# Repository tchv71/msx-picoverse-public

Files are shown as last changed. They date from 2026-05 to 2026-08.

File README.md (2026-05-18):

# PicoVerse for MSX

**The MSX experience driven by the Raspberry Pi Pico family of microcontrollers.**

PicoVerse is a community-driven effort to build versatile MSX cartridges powered by Raspberry Pi Pico development boards. The project pairs accessible hardware designs with ready-to-flash firmware so MSX users can jump straight into loading games, tools, and Nextor without having to compile sources.

| Cartridge Label - 2040 Variant | Cartridge Label - 2350 Variant |
|---|---|
|PicoVerse 2040 Label | PicoVerse 2350 Label |

PicoVerse is designed as an open-source, independent, and documented MSX cartridge platform. Compatibility with other projects is neither a goal nor guaranteed (I tested some without much success); running third‑party software on PicoVerse hardware, or PicoVerse firmware on other boards, is at your own risk. The source and manufacturing files are openly available so you can learn, experiment, and build on them for the MSX community, subject to the project license.

If you find any issues, have questions, or want to contribute, please open an issue or reach out via the contact information in the repository.

## Project Highlights

- Single-ROM LoadROM workflow for instant and easy booting of one title.
- Multi-ROM loader with an on-screen menu and mapper auto-detection.
- Explorer firmware (PicoVerse 2350) merges flash and microSD ROMs, labels the source (FL/SD), adds MP3 playback, supports on-device search, includes ROM detail audio profiles with SCC/SCC+ and Dual PSG support, and includes an integrated File Hunter browser for downloading ROMs over ESP-01 WiFi.
- Ready-made Nextor builds with USB pendrive (`-s2`/`-m2`) or microSD card (`-s1`/`-m1`) via Sunrise IDE emulation on PicoVerse 2350, and USB (`-s`/`-m`) on PicoVerse 2040.
- Sunrise IDE + 192KB memory mapper on PicoVerse 2040 (`loadrom.exe -m`), or Sunrise IDE standalone (`loadrom.exe -s`).
- Sunrise IDE + 1MB PSRAM memory mapper on PicoVerse 2350 (`loadrom.exe -m1` for microSD, `loadrom.exe -m2` for USB), or Sunrise IDE standalone (`loadrom.exe -s1` / `loadrom.exe -s2`).
- Carnivore2-compatible RAM-mode loader on PicoVerse 2350 (`loadrom.exe -c1` / `loadrom.exe -c2`) for `SROM.COM /D15` uploads into the 1MB PSRAM mapper.
- ESP-01 WiFi support for PicoVerse 2350 Sunrise IDE LoadROM/MultiROM builds (`loadrom.exe -s1 -w`, `-m1 -w`, `-s2 -w`, `-m2 -w`) and for the Explorer File Hunter browser. Compatible with both real MSX hardware and FPGA-based MSX cores.
- SCC/SCC+, Dual PSG, and MSX-MUSIC/YM2413 emulation on the PicoVerse 2350, with per-ROM audio profile selection where supported.
- PC-side tooling that generates UF2 images locally for quick drag-and-drop flashing.
- USB keyboard support on PicoVerse 2040 — use a standard USB keyboard as the MSX keyboard via the cartridge slot.
- MSX-MIDI support on PicoVerse 2040 — use a USB-MIDI cable as a standard MSX-MIDI interface via the cartridge slot. 
- MIDI-PAC support on PicoVerse 2040 — passively convert live MSX PSG music and effects into high-quality MIDI for external synths or sound modules (SC-55 optimized). Features automatic bass detection, tone+noise coexistence, smooth pitch bending on fast passages, and improved percussion mapping. 
- USB joystick support on PicoVerse 2040 — plug a standard USB gamepad (HID, Xbox 360, Xbox One, or Xbox Series X|S) into the USB-C port and it appears as one or two native MSX joysticks with no MSX-side software needed. Uses open-drain bus driving to coexist with the real PSG.
- BOMs, and production-ready Gerbers.
- Active development roadmap covering RP2040 and RP2350-based cartridges.

## Documentation

**LoadROM Guides:** Use the LoadROM tool to create a UF2 image that boots directly into a single ROM, skipping the menu. Mapper type is auto-detected with filename tag overrides, and the tool reports the detected configuration before flashing.
- [MSX PicoVerse 2040 LoadROM Tool Manual (English)](/docs/msx-picoverse-2040-loadrom-tool-manual.en-us.md) 
- [MSX PicoVerse 2350 LoadROM Tool Manual (English)](/docs/msx-picoverse-2350-loadrom-tool-manual.en-us.md) 
  
**MultiROM Guides:** Use the MultiROM tool to create a UF2 image that allows selecting from multiple ROMs at boot. Mapper type is auto-detected with filename tag overrides, and the tool reports the detected configuration before flashing.
- [PicoVerse 2040 MultiROM Guide Manual (English)](/docs/msx-picoverse-2040-multirom-tool-manual.en-us.md)
- [PicoVerse 2350 MultiROM Tool Manual (English)](/docs/msx-picoverse-2350-multirom-tool-manual.en-us.md)

**Explorer Guides:** Use the Explorer tool to manage flash and microSD ROMs, play MP3s, browse File Hunter over ESP-01 WiFi, and search for titles on the device.
- [MSX PicoVerse 2350 Explorer Tool Manual (English)](/docs/msx-picoverse-2350-explorer-tool-manual.en-us.md)

**Reference Material** 
- [PicoVerse 2040 Features Overview](/docs/msx-picoverse-2040-features.md)
- [PicoVerse 2350 Features Overview](/docs/msx-picoverse-2350-features.md)
- [MSX PicoVerse 2350 Dual PSG Implementation](/docs/msx-picoverse-2350-dualpsg.md)
- [MSX PicoVerse 2350 MSX-MUSIC/FM-PAC Implementation](/docs/msx-picoverse-2350-fmpac.md)
- [MSX PicoVerse 2350 WiFi Support](/docs/msx-picoverse-2350-wifi.md)
- [MSX PicoVerse 2040 PIO Strategy](/docs/msx-picoverse-2040-pio.md) 
- [MSX PicoVerse 2350 PIO Strategy](/docs/msx-picoverse-2350-pio.md) 
- [MSX PicoVerse 2350 SCC Emulation](/docs/msx-picoverse-2350-scc.md)
- [MSX PicoVerse 2040 Sunrise IDE Emulation for Nextor](/docs/msx-picoverse-2040-sunrise-nextor.md) 
- [MSX PicoVerse 2350 Sunrise IDE Emulation for Nextor](/docs/msx-picoverse-2350-sunrise-nextor.md) 
- [MSX PicoVerse 2040 Mapper Implementation (Sunrise + Nextor)](/docs/msx-picoverse-2040-mapper.md) 
- [MSX PicoVerse 2040 USB Keyboard](/docs/msx-picoverse-2040-keyboard.md)
- [MSX PicoVerse 2040 MSX-MIDI](/docs/msx-picoverse-2040-msx-midi.md) 
- [MSX PicoVerse 2040 MIDI-PAC](/docs/msx-picoverse-2040-midipac.md)
- [MSX PicoVerse 2040 MegaROMs](/docs/msx-picoverse-2040-megaroms.md)
- [MSX PicoVerse 2040 USB Joystick](/docs/msx-picoverse-2040-joystick.md)

## Hardware Variants

### PicoVerse 2040 Cartridge

| Prototype PCB (front) | Prototype PCB (back) |
|---|---|
|  |  | 

- Based on RP2040 boards exposing 30 GPIO pins (not compatible with stock Raspberry Pi Pico pinout).
- Up to 16 MB of flash for MSX ROMs with support for Plain16/32 (`PLA-16`/`PLA-32`), Planar48/64 (`PLN-48`/`PLN-64`), Konami SCC, Konami, ASCII8/16/16X, NEO-8, NEO-16, and Manbow2 (`MANBW2`) mappers.
- USB-C port doubles as a bridge for Nextor mass storage via Sunrise IDE emulation (`loadrom.exe -s`).
- Sunrise IDE + 192KB memory mapper mode provides both Nextor disk access and expanded RAM (`loadrom.exe -m`).
- Standalone USB keyboard firmware — use a standard USB keyboard as the MSX keyboard via the cartridge slot (`loadrom.exe -k`). Not compatible with FPGA-based MSX systems or MSX computers with an integrated PPI (e.g. T9769 MSX-ENGINE).
- Standalone MSX-MIDI firmware — use a USB-MIDI cable as a standard MSX-MIDI interface for MIDI players and sequencers (`loadrom.exe -i`).
- Standalone MIDI-PAC firmware — passively listen to the MSX PSG and convert music and effects to USB MIDI for an external synth or sound module (`loadrom.exe -p`).
- Standalone USB joystick firmware — use a standard USB gamepad as an MSX joystick via the cartridge slot (`loadrom.exe -j`). Supports Xbox 360, Xbox One, Xbox Series X|S, and generic USB HID gamepads, with up to 2 gamepads mapped to MSX joystick ports 1 and 2.  Not compatible with FPGA-based MSX systems or MSX computers with an integrated PSG (e.g. T9769 MSX-ENGINE).

#### Bill of Materials



Interactive BOM available at [PicoVerse 2040 BOM](https://htmlpreview.github.io/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)

| Reference | Description | Quantity | Link |
| --- | --- | --- | --- |
| U1 | RP2040 Dev Board 30 GPIO pins exposed | 1 | [AliExpress](https://s.click.aliexpress.com/e/_c4MuM9st) |
| C1 | 0603 0.1 µF Ceramic Capacitor | 1 | [AliExpress](https://s.click.aliexpress.com/e/_c2w5e36V) |
| C2 | 0603 10 µF Ceramic Capacitor | 1 | [AliExpress](https://s.click.aliexpress.com/e/_c2w5e36V)|
| R2, R3, R4, R5, R6, R7, R8, R9, R10, R11, R12, R13| 0603 10 kΩ Resistor | 12 | [AliExpress](https://s.click.aliexpress.com/e/_c3XBv4od)|
| R1 | 0603 2 KΩ Resistor | 1 | [AliExpress](https://s.click.aliexpress.com/e/_c3XBv4od)|
| D1 | 1N5819 SOD-123 Diode | 1 | [AliExpress](https://s.click.aliexpress.com/e/_c4WEKCuz) |
| Q1, Q2, Q3, Q4, Q5 | BSS138 SOT-23 Transistor | 5 | [AliExpress](https://s.click.aliexpress.com/e/_c2veWxcD)|

### PicoVerse 2350 Cartridge

| Prototype PCB (front) | Prototype PCB (back) |
|---|---|
|  |  |

- Targets RP2350 boards exposing all 48 GPIO pins (not compatible with standard Pico 2 boards).
- Adds microSD storage, ESP8266 WiFi header, and I2S audio expansion alongside 16 MB flash space.
- Extra RAM (PSRAM) now backs the 1MB mapper modes and the Carnivore2-compatible RAM loader, with room for additional advanced firmware features.
- Explorer firmware can load ROMs from both flash and microSD, browse File Hunter over ESP-01 WiFi, save downloaded File Hunter ROMs to the microSD root, search local title lists, and select SCC/SCC+ or Dual PSG audio profiles per ROM where supported.
- USB-C port doubles as a bridge for Nextor mass storage via Sunrise IDE emulation (`-s2`).
- microSD card slot provides Nextor mass storage via Sunrise IDE emulation (`-s1`).
- Sunrise IDE + 1MB PSRAM memory mapper mode provides both Nextor disk access and expanded RAM (`-m1` for microSD, `-m2` for USB).
- Carnivore2-compatible RAM-mode loading lets `SROM.COM /D15` upload ROMs into the 1MB PSRAM mapper (`-c1` for microSD, `-c2` for USB).
- LoadROM Sunrise builds can also expose ESP-01 WiFi support with `-w` on top of the `-s1`/`-m1`/`-s2`/`-m2` modes.
- Both LoadROM and MultiROM tools support the Sunrise IDE options; MultiROM allows combining them so multiple Nextor modes appear as selectable SYSTEM entries in the menu.
- Shares the same ROM mapper support list as the 2040 build.

#### Bill of Materials



Interactive BOM available at [PicoVerse 2350 BOM](https://htmlpreview.github.io/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) 

| Reference | Description | Quantity | Link |
| --- | --- | --- | --- |
| U1 | WaveShare Core2350B Dev Board 48 GPIO pins exposed (8Mb PSRAM)| 1 | [AliExpress](https://pt.aliexpress.com/item/1005009578742534.html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) |
|U2| UDA1334A I2S Stereo DAC| 1 | [AliExpress](https://s.click.aliexpress.com/e/_c3gam5lH) |
|U3| ESP-01 ESP8266 WiFi Module| 1 | [AliExpress](https://s.click.aliexpress.com/e/_c4a5rnGj) |
|C1| 0603 0.1 µF Ceramic Capacitor | 1 | [AliExpress](https://s.click.aliexpress.com/e/_c3tkUxHz) |
|C2,C3| 0603 10 µF Ceramic Capacitor | 2 | [AliExpress](https://s.click.aliexpress.com/e/_c3tkUxHz)|
|R1| 0603 2 KΩ Resistor | 1 | [AliExpress](https://s.click.aliexpress.com/e/_c43uKcEj)|
|R2, R3, R6, R7, R8| 0603 10 kΩ Resistor | 4 | [AliExpress](https://s.click.aliexpress.com/e/_c43uKcEj)|
|R4, R5| 0603 5.1 kΩ Resistor | 2 | [AliExpress](https://s.click.aliexpress.com/e/_c43uKcEj)|
|R9, R10| 0603 330 Ω Resistor | 2 | [AliExpress](https://s.click.aliexpress.com/e/_c43uKcEj)|
|D1| 1N5819 SOD-123 Diode | 1 | [AliExpress](https://s.click.aliexpress.com/e/_c4WEKCuz) |
|SW1| Tactile Push Button Switch | 1 | [AliExpress](https://s.click.aliexpress.com/e/_c2IPGkzv) |
|J1| USB-C 16 Pin Connector | 1 | [AliExpress](https://s.click.aliexpress.com/e/_c4PtBc51) |
|J2| microSD Card Slot | 1 | [AliExpress](https://s.click.aliexpress.com/e/_c4Pzbd7Z) |

## Repository Contents
- `hardware/` – Production-ready Gerbers, fabrication notes, and BOMs for each supported dev board.
- `software/` – MultiROM PC utilities (`multirom.exe`) and menu ROM assets for both cartridge families.
- `docs/` – Feature lists, usage walkthroughs, and revision history for each cartridge family.
- `images/` – Board renders and build photos for quick identification.
- `labels/` – Printable Patola style cartridge label designs for both hardware variants.

## Quick Start
1. **Pick your target board**: Select the hardware revision that matches the RP2040 or RP2350 carrier you own, then grab the corresponding Gerber/BOM pack.
2. **Manufacture or assemble**: Send the Gerbers to your PCB house or build from an ordered kit. Follow the assembly notes included in each hardware bundle.
3. **Generate the UF2 image**:
   - For multiple titles, place your `.rom` files beside the MultiROM tool for your cartridge family (`2040/software/multirom.pio/tool/multirom.exe` or `2350/software/multirom.pio/tool/multirom.exe`) and run `multirom.exe` to create `multirom.uf2`.
   - For an instant boot into a single game, place the desired `.rom` next to the LoadROM tool for your cartridge family and run `loadrom.exe <file> [-o custom.uf2]` to create a dedicated UF2 that skips the menu.
   - For a combined flash + microSD menu (on PicoVerse 2350 only), use the Explorer tool (`2350/software/explorer.pio/tool/explorer.exe`) to create `explorer.uf2`, then copy extra `.rom` and `.mp3` files to the microSD card. With an ESP-01 module and configured WiFi, Explorer can also browse File Hunter and save downloaded ROMs directly to the microSD root.
4. **Flash the firmware**:
   - Hold BOOTSEL while connecting the cartridge to your PC via USB-C.
   - Copy the freshly generated UF2 (`multirom.uf2`, `loadrom.uf2`, or `explorer.uf2`) to the RPI-RP2 drive that appears.
   - Eject the drive; the board reboots and stores the image in flash.
5. **Enjoy on MSX**: Insert the cartridge, power on the computer, pick a ROM from the menu, or launch Nextor to access USB or microSD storage.

## MultiROM Menu

| PicoVerse 2040 MultiRom | PicoVerse 2350 MultiRom |
|---|---|
|PicoVerse 2040 MultiROM menu|PicoVerse 2350 MultiROM menu|

To use the MultiROM menu, insert the PicoVerse cartridge into your MSX and power it on. The system will boot directly into the MultiROM menu, which displays a list of all ROMs embedded in the cartridge. Each entry is named after the ROM filename (up to 50 characters), and longer names are shown using a scrolling effect.

Navigate the menu using the keyboard arrow keys. Use the Up and Down keys to move through the list of ROMs, and if more than 19 ROMs are present, use the Left and Right keys to switch between pages. To start a game or application, select it and press Enter or Space; the MSX will boot the ROM using the appropriate mapper configuration automatically.

While in the menu, pressing the H key opens a help screen with basic instructions; press any key to return to the main menu. Once a ROM is launched, control is handed over entirely to the selected software, just as if it were a physical cartridge inserted into the MSX.

Check the detailed MultiROM guide in the documentation folder for advanced features, troubleshooting tips, and mapper support details.

## LoadROM Tool

The LoadROM tool targets situations where you want the PicoVerse to behave like a traditional single-game cartridge or as a dedicated standalone firmware image. Instead of showing the MultiROM menu, the Pico boots straight into one ROM embedded in the UF2 image, or into a selected standalone mode such as keyboard, MSX-MIDI, MIDI-PAC, or USB joystick.

- **Input**: exactly one `.ROM` file. Mapper type is auto-detected with the same heuristics as MultiROM, and you can still force a mapper via filename tags such as `.KonSCC.ROM` or `.PLA-32.ROM`.
- **Output**: `loadrom.uf2` by default, or any filename you pass via `-o`. The UF2 contains the firmware, a 59-byte configuration record (title, mapper, size, flash offset), and the ROM payload.
- **Workflow**:
   1. Open a Command Prompt or PowerShell window in your target package folder:
      - `2040/software/loadrom.pio/tool`, or
      - `2350/software/loadrom.pio/tool`.
   2. Run `loadrom.exe -o mygame.uf2 \\path\\to\\Game.ROM` (the tool also accepts drag-and-drop onto the EXE).
      - MSX-MIDI standalone mode: `loadrom.exe -i -o midi.uf2`
      - MIDI-PAC standalone mode: `loadrom.exe -p -o midipac.uf2`
      - USB joystick standalone mode: `loadrom.exe -j -o joystick.uf2`
      - SCC standard emulation (only PicoVerse 2350): `loadrom.exe -scc \\path\\to\\Game.ROM`
      - SCC+ enhanced emulation (only PicoVerse 2350): `loadrom.exe -sccplus \\path\\to\\Game.ROM`
      - MSX-MUSIC/FM-PAC emulation with the bundled English FM-PAC BIOS (only PicoVerse 2350, non-SYSTEM ROMs): `loadrom.exe -f \\path\\to\\Game.ROM`, `loadrom.exe -fmpac \\path\\to\\Game.ROM`, or `loadrom.exe --fmpac -o mygame-fmpac.uf2 \\path\\to\\Game.ROM`
      - Dual PSG emulation on secondary PSG ports `0x10`/`0x11` (only PicoVerse 2350, supported non-SYSTEM ROMs): `loadrom.exe -d \\path\\to\\Game.ROM` or `loadrom.exe --dual-psg -o mygame-dualpsg.uf2 \\path\\to\\Game.ROM`
      - `-scc` and `-sccplus` are mutually exclusive.
      - `-scc`, `-sccplus`, `-f` / `-fmpac`, and `-d` / `--dual-psg` are cartridge audio modes; use only one of them per UF2.
      - `-f` / `-fmpac` is not valid with Sunrise or Carnivore2 system modes (`-s1`, `-m1`, `-s2`, `-m2`, `-c1`, or `-c2`) or with Konami SCC / Manbow2 mapper ROMs.
      - `-d` / `--dual-psg` is intended for software that writes to a second PSG. It is not available for Konami SCC or Manbow2 mapper ROMs, SCC/SCC+ audio builds, Sunrise/Nextor system modes, or Carnivore2 system modes.
      - Sunrise IDE standalone (PicoVerse 2040): `loadrom.exe -s`
      - Sunrise IDE + 192KB mapper (PicoVerse 2040): `loadrom.exe -m`
      - Sunrise IDE standalone (PicoVerse 2350): `loadrom.exe -s1` or `loadrom.exe -s2`
      - Sunrise IDE + 1MB PSRAM mapper (PicoVerse 2350): `loadrom.exe -m1` or `loadrom.exe -m2`
      - Sunrise IDE + WiFi (PicoVerse 2350): `loadrom.exe -s1 -w`, `loadrom.exe -s2 -w`, `loadrom.exe -m1 -w`, or `loadrom.exe -m2 -w`
      - Carnivore2-compatible RAM loader (PicoVerse 2350): `loadrom.exe -c1` or `loadrom.exe -c2`
      - `-w` is currently supported only with `-s1`, `-m1`, `-s2`, or `-m2`.
   3. Observe the reported ROM name, size, mapper status (auto vs forced), and Pico offset before the UF2 is written.
   4. Put the Pico into BOOTSEL mode and copy the generated UF2 to the `RPI-RP2` drive.
   5. Insert the cartridge into your MSX—on power-up the embedded game launches immediately.

Consult the LoadROM manuals linked above for screenshots, troubleshooting, and in-depth explanations of mapper forcing, UF2 structure, and limitations.

## Explorer Firmware (RP2350)

|Explorer Flash Menu|Explorer MicroSD Menu|
|---|---|
|Explorer flash menu|Explorer microSD menu|
|<center>**File Hunter Explorer Menu**|<center>**WiFi Configuration Screen**|
|File Hunter Explorer menu|WiFi configuration screen|

Explorer is a PicoVerse 2350-only firmware that merges ROMs stored in flash with additional ROMs and MP3 files on the microSD card. ROMs are labeled with source tags (FL/SD), MP3 entries open a player screen, the list supports paging, and you can search by name directly in the menu. With an ESP-01 / ESP8266 module installed and WiFi configured, pressing `F3` opens the integrated File Hunter browser. File Hunter results show the ROM name and size, can be searched from the MSX, and selected ROMs are downloaded through the Pico into PSRAM before being saved as `.ROM` files in the microSD root. microSD ROMs up to 2 MB can be executed directly from there. Use the Explorer tool to build the UF2 and copy extra ROMs and MP3 files to the microSD card. See the Explorer manual for limits (flash vs SD capacity, 2 MB SD ROM limit, File Hunter requirements, and supported formats).

You can have up to 1024 entries per folder view (folders + ROMs + MP3s; the root view can also include flash entries). The menu auto-detects whether the MSX supports 80-column text mode and boots accordingly; you can also press `C` at any time to toggle between 40- and 80-column layouts.

Explorer ROM entries open a detail screen where you can inspect mapper detection and choose a cartridge audio profile. For supported non-SYSTEM ROMs, select **Dual PSG** and run the ROM to enable the second cartridge-side PSG on ports `0x10` and `0x11`. Explorer hides or rejects Dual PSG where the second cartridge audio slot is reserved, including Konami SCC, Manbow2, SYSTEM entries, folders, and File Hunter folder records. 

A search function is available by pressing `/` in the menu. Type part of a ROM name and press Enter to jump to the first matching entry. Press `H` to view the help screen.

The File Hunter browser was implemented with reference to NataliaPC's public MSX File Hunter Browser project: https://github.com/nataliapc/msx_filehunterbrowser

## Compatibility & Requirements

- Works with MSX, MSX2, MSX2+, and MSX TurboR systems. Mapper support covers the most common game and utility formats.
- Requires Windows OS to run the PC-side UF2 builder utilities.
- Ensure your development board matches the pinout documented for each hardware revision before soldering.

## License, Copyright notes & Usage

Creative Commons Attribution-NonCommercial-ShareAlike 4.0

All hardware and firmware binaries in this repository are released under the Creative Commons Attribution-NonCommercial-ShareAlike 4.0 International license. Personal builds and community tinkering are encouraged, but **commercial use or resale requires explicit authorization from the author**.

**bios.h** is used on all MSX menus and was adapted from http://www.konamiman.com/msx/msx2th/th-ap.txt by Danilo Angelo, 2020. The original file is licensed under CC0 1.0 Universal (public domain). The adapted bios.h file in this repository is also released under CC0 1.0 Universal, allowing for free use and modification without restrictions.

**msxromcrt0.s** is used on Nextor C implementation and was adapted by S0urceror, 2022, from the crt0.s file available in FusionC v2.0. The original crt0.s file is licensed under the MIT License. The adapted msxromcrt0.s file in this repository is also released under the MIT License, permitting free use, modification, and distribution with proper attribution.

**uf2format.h** is used in all UF2 builder tools and was adapted from the UF2 specification and reference implementation available at https://github.com/Microsoft/uf2/blob/master/uf2.h. The original uf2.h is copyright by Microsoft Corp and the file is licensed under the MIT License. The adapted uf2format.h file in this repository is also released under the MIT License, allowing for free use, modification, and distribution with proper attribution.

**emu2212.c** and **emu2212.h** used to implement SCC and SCC+ emulation are copyright by Mitsutaka Okazaki 2014 and licensed under the MIT License, allowing for free use, modification, and distribution with proper attribution. [emu2212 @ Digital Sound Antiques](https://github.com/digital-sound-antiques/emu2212)

**emu2149.c** and **emu2149.h** used to implement AY-3-8910 emulation/dual PSG feature are copyright by Mitsutaka Okazaki 2014 and licensed under the MIT License, allowing for free use, modification, and distribution with proper attribution. [emu2149 @ Digital Sound Antiques](https://github.com/digital-sound-antiques/emu2149)

**emu2413.c** and **emu2413.h** used to implement YM2413 / MSX-MUSIC emulation are copyright by Mitsutaka Okazaki 2020 and licensed under the MIT License, allowing for free use, modification, and distribution with proper attribution. [emu2413 @ Digital Sound Antiques](https://github.com/digital-sound-antiques/emu2413)

**FMPCCMFC.BIN** is the English FM-PAC BIOS used by PicoVerse 2350 LoadROM when `-f` / `-fmpac` is selected. The FM-PAC BIOS ROM is copyrighted by Matsushita Corp.; the English translation is credited to 232, Max Iwamoto, and GDX.

**MIDI-PAC PSG-to-MIDI Conversion:**  
The MIDI-PAC firmware and its quality improvements were developed against public technical references and behavior studies. The PSG-to-MIDI mapping combines hardware-correct AY-3-8910 / YM2149 interpretation with pragmatic General MIDI reinterpretation for musical output on modules like the Roland SC-55. Key references used include:  
- The `berarma/aymidi` project by berarma (AY-3-8910 to MIDI conversion reference).  
- The `ayumi` AY/YM2149 emulator by Peter Sovietov (Peter Sovietov, 2022; used for envelope generation verification).  
- The ESEMSX3 FPGA implementation `midi.vhd` (serves as a minimal alternative PSG-to-MIDI transport reference).  
- AY-3-8910 and YM2149 datasheets and hardware behavior documentation (General Instruments and Yamaha specifications).  
- MSX-MIDI specification and USB MIDI 1.0 Event Packet format (USB Implementers Forum).  
- The Sunrise IDE specification and Nextor protocol documentation.  

These references informed structure, timing, envelope shapes, and musical mapping decisions. The PicoVerse firmware maintains its own implementation with no dependencies on external emulation libraries. The PicoVerse files are licensed under CC BY-NC-SA 4.0, allowing for non-commercial use and modification with proper attribution, but commercial use or resale requires explicit authorization from the author.

**MSX-MIDI Interface:**  
The MSX-MIDI firmware was developed using the MSX-MIDI specification, USB MIDI 1.0 specification, TinyUSB host API, and reference behavior from ESEMSX3 and similar implementations. The 8251 USART emulation and standard MIDI wire protocol handling are original PicoVerse implementations.

**The Sunrise IDE driver for Nextor** used on PicoVerse is copyright by Konamiman, Piter Punk, and FRS, and is licensed under the special terms by MSX Licensing Corporation. The original Sunrise IDE code is available at https://github.com/Konamiman/Nextor/blob/v2.1/source/kernel/drivers/SunriseIDE/sunride.asm

The algorithm to emulate ATA devices is original and based on the implementation for the Carnivore2 cartridge, Copyright (c) 2017-2024 by the RBSC group. Portions (c) Mitsutaka Okazaki and (c) Kazuhiro Tsujikawa. Available at https://github.com/RBSC/Carnivore2/tree/master/Firmware/Sources

**WiFi support on PicoVerse 2350** was implemented with direct reference to the ESP8266 / MSX WiFi work by Oduvaldo Pavan Junior (`ducasp`). The PicoVerse WiFi ROM integration, memio register layout, fixed-`859372` UART behavior, FIFO clear command handling, quick-receive behavior, and ESP-side protocol compatibility were based on public source and documentation from Oduvaldo's projects. Important references used include:
- `MSXPICO/UNAPI_BIOS_CUSTOM_ESP_MSXPICO/ESP8266_memio.asm` from `ducasp/MSX-Development` for the memory-mapped ROM and register model.
- `MSX-SM/WiFi/UNAPI_BIOS_CUSTOM_ESP_FIRMWARE` and related WiFi utilities from `ducasp/MSX-Development` for the ROM/driver lineage and behavior.
- `ducasp/ESP8266-UNAPI-Firmware` and its documentation for the serial protocol, command/response structure, and ESP firmware behavior.

Those projects remain copyright by Oduvaldo Pavan Junior and their respective contributors under their original terms. PicoVerse reuses the public technical design references and keeps its own RP2350 cartridge-side implementation.

**File Hunter browser integration on PicoVerse 2350 Explorer** was implemented with reference to NataliaPC's MSX File Hunter Browser project and the public File Hunter service behavior. PicoVerse keeps its own Explorer MSX menu and RP2350/ESP8266 transport implementation, while acknowledging the original MSX File Hunter Browser code and workflow by NataliaPC. Reference repository: https://github.com/nataliapc/msx_filehunterbrowser

**Mapper detection heuristics and filename tag forcing schemes** in the LoadROM and MultiROM tools are original implementations by the OpenMSX developers for the Romfactory module and licensed under the GNU Public License (GPL). Available at https://github.com/openMSX/openMSX/blob/6f8aa9865eeccdb0b31043d8851b822538440204/src/memory/RomFactory.cc

**The softwaredb database** used for ROM mapper detection is built upon contributions from across the MSX community, including the initial work by Nicolas Beyaert, later expanded by the BlueMSX Team (2004–2013) and continuously maintained by the openMSX Team (2005–present). It also incorporates MSX ID data generated by Generation MSX (www.generation-msx.nl). Special thanks go to the Generation MSX / Sylvester project for its extensive reference data, as well as to contributors such as p_gimeno and diedel for ROM additions and validation, and GDX for further ROM information, corrections, and verification efforts. Part of OpenMSX effort. Available at https://github.com/openMSX

## Feedback & Community

Questions, test reports, and build photos are welcome. Open an issue on the public repository or reach out through the MSX retro hardware forums where PicoVerse updates are posted.

Author: Cristiano Goncalves
Last updated: 05/17/2026

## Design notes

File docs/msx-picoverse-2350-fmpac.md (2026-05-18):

# MSX PicoVerse 2350 - MSX-MUSIC / FM-PAC Implementation

The PicoVerse 2350 LoadROM firmware can emulate the MSX-MUSIC YM2413 sound chip and expose an FM-PAC compatible BIOS area for games that do not drive the YM2413 directly. This is enabled by the LoadROM tool options `-f`, `-fmpac`, or `--fmpac` when building a UF2 for a non-SYSTEM external ROM.

The implementation has two parts:

- Pico-side YM2413 synthesis using the emu2413 OPLL emulator and the PicoVerse I2S DAC.
- FM-PAC BIOS exposure in the cartridge slot so software that uses MSX-MUSIC BIOS calls can find the BIOS routines and reach the emulated OPLL.

This document describes the RP2350 LoadROM implementation in `2350/software/loadrom.pio`.

---

## Goals

The FM-PAC/MSX-MUSIC support was added for ROMs that expect MSX-MUSIC hardware to be present on the cartridge. Some titles write directly to the YM2413 I/O ports, while others use BIOS routines or FM-PAC memory-mapped registers. The firmware supports both access styles.

The design goals are:

- Keep MSX-MUSIC as a single cartridge audio profile, mutually exclusive with SCC, SCC+, and Dual PSG.
- Allow `-f` / `-fmpac` with supported non-SYSTEM external ROM mappers, excluding SCC-class mappers.
- Embed the FM-PAC BIOS in the UF2 image, immediately after the game ROM payload.
- Present the selected game ROM mapper and the FM-PAC BIOS in one expanded cartridge slot layout.
- Route both direct YM2413 I/O writes and FM-PAC memory-mapped register writes to the same OPLL emulator instance.

---

## User-facing behavior

### Command-line options

```
loadrom.exe -f <romfile>
loadrom.exe -fmpac <romfile>
loadrom.exe --fmpac <romfile>
```

All three options enable the same feature. The tool prints:

```
MSX-MUSIC/FM-PAC Emulation: Enabled with BIOS and YM2413 ports 0x7C/0x7D
```

### Valid combinations

`-f` / `-fmpac` is valid only with non-SYSTEM external ROM files. It is rejected for the embedded Sunrise/Carnivore2 system modes (`-s1`, `-m1`, `-s2`, `-m2`, `-c1`, `-c2`) and for Konami SCC or Manbow2 mapper ROMs.

Only one cartridge audio engine can be active in a UF2 image. The tool rejects combinations of:

- `-scc`
- `-sccplus`
- `-d` / `--dual-psg`
- `-f` / `-fmpac` / `--fmpac`

Konami SCC and Manbow2 mapper ROMs are not accepted for `-f` / `-fmpac` builds.

---

## Source files

### Tool side

| File | Role |
| --- | --- |
| `2350/software/loadrom.pio/tool/src/loadrom.c` | Parses `-f` / `-fmpac`, sets the MSX-MUSIC flag, appends the FM-PAC BIOS payload, and writes the UF2. |
| `2350/software/loadrom.pio/tool/Makefile` | Generates `tool/src/fmpac_bios.h` from `../fmpac/FMPCCMFC.BIN` using `utils/xxd -i`. |
| `2350/software/loadrom.pio/tool/src/fmpac_bios.h` | Generated C array containing the 64 KB FM-PAC BIOS. |
| `2350/software/loadrom.pio/fmpac/FMPCCMFC.BIN` | English FM-PAC BIOS binary embedded into `-f` / `-fmpac` UF2 images. |

### Firmware side

| File | Role |
| --- | --- |
| `2350/software/loadrom.pio/pico/loadrom/loadrom.c` | Implements audio mode selection, YM2413 initialization, direct I/O handling, FM-PAC register handling, and the expanded-slot FM-PAC mapper wrapper. |
| `2350/software/loadrom.pio/pico/loadrom/loadrom.h` | Defines MSX-MUSIC flags, ports, clocks, sample rate, and FM-PAC BIOS size. |
| `2350/software/loadrom.pio/pico/loadrom/emu2413.c` | YM2413/OPLL emulator implementation. |
| `2350/software/loadrom.pio/pico/loadrom/emu2413.h` | YM2413/OPLL emulator API. |
| `2350/software/loadrom.pio/pico/loadrom/CMakeLists.txt` | Includes `emu2413.c` in the LoadROM firmware build. |

---

## Build integration

The top-level LoadROM build is driven by `2350/software/loadrom.pio/Makefile`.

The PC tool build depends on the FM-PAC BIOS binary:

```
FMPAC_BIOS := ../fmpac/FMPCCMFC.BIN
FMPAC_BIOS_H := $(SRCDIR)/fmpac_bios.h
```

The header is generated with the local `xxd` utility:

```
$(FMPAC_BIOS_H): $(FMPAC_BIOS)
	$(UTLDIR)/$(XXD) -i $< $@
```

The generated symbol names are:

```
___fmpac_FMPCCMFC_BIN[]
___fmpac_FMPCCMFC_BIN_len
```

The current BIOS payload length is 65536 bytes.

---

## UF2 payload layout

LoadROM UF2 images are written by `create_uf2_file()` in the tool. With `-f` / `-fmpac`, the binary stream is:

| Order | Payload | Description |
| --- | --- | --- |
| 1 | Firmware blob | RP2350 LoadROM firmware from `pico/loadrom/dist/loadrom.bin`. |
| 2 | Configuration record | 59-byte record containing ROM name, mapper/audio flags, ROM size, and ROM flash offset. |
| 3 | Game ROM | The external ROM file passed on the command line. |
| 4 | FM-PAC BIOS | `FMPCCMFC.BIN`, appended only when MSX-MUSIC/FM-PAC is enabled. |

The firmware uses the game ROM size from the configuration record to find the BIOS:

```
fmpac_bios_base = rom + offset + active_rom_size
```

This keeps the existing ROM payload format intact while reusing the extra embedded ROM mechanism already used by other LoadROM modes.

---

## Configuration flags

The configuration record stores mapper and audio selection in one byte. For non-SYSTEM ROMs, bit `0x20` is used as the MSX-MUSIC flag:

| Bit | Firmware constant | Meaning in non-SYSTEM ROM builds |
| --- | --- | --- |
| `0x80` | `SCC_FLAG` | SCC emulation requested. |
| `0x40` | `SCC_PLUS_FLAG` | SCC+ emulation requested. |
| `0x20` | `MSX_MUSIC_FLAG` | MSX-MUSIC / FM-PAC requested. |
| `0x10` | `DUAL_PSG_FLAG` | Dual PSG requested. |
| `0x0F` | Base mapper ID | Selected ROM mapper. |

The same `0x20` bit is used as `WIFI_FLAG` in Sunrise system modes. The firmware distinguishes those cases by checking the base ROM type and resolving `system_mode` before selecting an audio engine.

---

## Audio mode selection

The firmware resolves cartridge audio through `resolve_audio_mode()`.

The modes are:

| Mode | Meaning |
| --- | --- |
| `AUDIO_MODE_NONE` | No Pico-side cartridge audio engine. |
| `AUDIO_MODE_SCC` | Standard SCC emulation. |
| `AUDIO_MODE_SCC_PLUS` | SCC+ emulation. |
| `AUDIO_MODE_DUAL_PSG` | Secondary AY-3-8910 on ports `0x10`/`0x11`. |
| `AUDIO_MODE_MSX_MUSIC` | YM2413/MSX-MUSIC on ports `0x7C`/`0x7D` plus FM-PAC BIOS exposure. |

System ROM modes always resolve to `AUDIO_MODE_NONE` for this path. Because the tool enforces mutual exclusion, a valid `-f` / `-fmpac` image contains only the MSX-MUSIC flag and therefore resolves to `AUDIO_MODE_MSX_MUSIC`.

When `AUDIO_MODE_MSX_MUSIC` is selected, `main()` initializes the YM2413 engine and then dispatches to `loadrom_fmpac()` before the normal mapper switch.

---

## YM2413 / OPLL audio engine

### Emulation library

The firmware uses emu2413 by Mitsutaka Okazaki. Initialization creates one OPLL instance:

```
OPLL_new(MSX_MUSIC_CLOCK, MSX_MUSIC_SAMPLE_RATE)
OPLL_setChipType(..., OPLL_2413_TONE)
OPLL_resetPatch(..., OPLL_2413_TONE)
```

The LoadROM constants are:

| Constant | Value |
| --- | --- |
| `MSX_MUSIC_CLOCK` | 3579545 Hz |
| `MSX_MUSIC_SAMPLE_RATE` | 44100 Hz |
| `MSX_MUSIC_PORT_REG` | `0x7C` |
| `MSX_MUSIC_PORT_DATA` | `0x7D` |

### Core usage

| Core | Role |
| --- | --- |
| Core 0 | Serves the MSX memory bus through PIO0 and routes FM-PAC memory-mapped writes to the OPLL. |
| Core 1 | Generates YM2413 audio, services direct OPLL I/O writes from PIO1, and feeds the I2S DAC. |

The audio path uses the existing PicoVerse I2S output on GPIOs 29-32:

| Signal | GPIO |
| --- | --- |
| DATA | 29 |
| BCLK | 30 |
| WSEL / LRCLK | 31 |
| MUTE | 32 |

### Locking

Both direct I/O writes and memory-mapped FM-PAC writes can reach the OPLL while core 1 is calculating audio samples. The firmware protects the OPLL instance with a Pico SDK spin lock:

- `msx_music_calc_sample()` locks around `OPLL_calc()`.
- `msx_music_write_io()` locks around `OPLL_writeIO()`.

This keeps core 0 register writes and core 1 audio generation from mutating the emulator state at the same time.

---

## Direct YM2413 I/O handling

The firmware initializes a PIO1 I/O bus captor with `msx_pio_io_bus_init()` when MSX-MUSIC is enabled.

`msx_music_service_io()` consumes captured I/O writes. Writes to ports `0x7C` and `0x7D` are forwarded to:

```
msx_music_write_io(port, data)
```

I/O reads are acknowledged with `0xFF`. The YM2413 path currently only needs write capture for register select and data writes.

When audio generation is running on core 1, direct I/O servicing is owned by core 1. This prevents missed port writes while core 0 is busy serving ROM or mapper cycles.

---

## FM-PAC expanded slot model

The firmware presents FM-PAC builds as an expanded cartridge slot. This follows the same general strategy used by Sunrise/Carnivore2-style expanded-slot modes, but with the game mapper and FM-PAC BIOS sharing the slot.

`loadrom_fmpac()` starts by waiting for the expanded-slot bootstrap, freezes the bus with `/WAIT`, prepares the ROM source/cache, then reinitializes the PIO0 MSX memory bus.

The expanded slot layout is:

| Subslot | Function |
| --- | --- |
| 0 | Selected game ROM mapper. |
| 1 | Unused, returns `0xFF`. |
| 2 | Unused, returns `0xFF`. |
| 3 | FM-PAC BIOS, FM-PAC control/page registers, PAC SRAM window, and memory-mapped OPLL write registers. |

The expanded slot selection register is handled at address `0xFFFF`. Writes update the local `subslot_reg`; reads return the inverted value, matching the standard expanded-slot register behavior.

For each read or write, the firmware computes the active subslot for the current 16 KB page:

```
page = address >> 14
active_subslot = (subslot_reg >> (page * 2)) & 0x03
```

If the active subslot is 0, the access is routed to the game mapper. If the active subslot is 3, the access is routed to the FM-PAC handler.

---

## FM-PAC memory map

The FM-PAC side is modeled by `fmpac_state_t`:

| Field | Purpose |
| --- | --- |
| `page` | Low two bits select one 16 KB page from the 64 KB BIOS. |
| `control` | Value stored by writes to `0x7FF6`; initialized to `0x10`. |
| `sram_key_5ffe` | First PAC SRAM enable key byte. |
| `sram_key_5fff` | Second PAC SRAM enable key byte. |
| `sram[8192]` | Volatile 8 KB PAC SRAM window. |

### Registers and windows

| Address/range | Access | Behavior |
| --- | --- | --- |
| `0x4000`-`0x7FFF` | Read | FM-PAC BIOS page selected by `0x7FF7`, unless PAC SRAM is enabled for `0x4000`-`0x5FFF`. |
| `0x4000`-`0x5FFF` | Read/write | Volatile PAC SRAM when keys `0x5FFE = 0x4D` and `0x5FFF = 0x69` are active. |
| `0x5FFE` | Write | Stores PAC SRAM key byte `0x4D`. |
| `0x5FFF` | Write | Stores PAC SRAM key byte `0x69`. |
| `0x7FF4` | Write | FM-PAC memory-mapped YM2413 register select; forwarded as port `0x7C`. |
| `0x7FF5` | Write | FM-PAC memory-mapped YM2413 data; forwarded as port `0x7D`. |
| `0x7FF6` | Read/write | FM-PAC control register shadow. |
| `0x7FF7` | Read/write | BIOS page register; low two bits select one of four 16 KB pages. |

The BIOS lookup is:

```
relative = ((page & 0x03) << 14) | (address & 0x3FFF)
```

Because `FMPAC_BIOS_SIZE` is 65536 bytes, the four pages cover the whole embedded BIOS.

---

## Supported game mappers inside FM-PAC mode

`loadrom_fmpac()` keeps the selected game mapper active in subslot 0. The mapper ID is still selected by the normal LoadROM detection/forcing path; `-f` / `-fmpac` only changes the audio and slot wrapper.

| Mapper ID | Mapper | FM-PAC wrapper behavior |
| --- | --- | --- |
| 1 | Plain 16 KB | Serves the fixed ROM window through the plain mapper path. |
| 2 | Plain 32 KB | Serves the fixed ROM window through the plain mapper path. |
| 3 | Konami SCC mapper | Not supported for FM-PAC/MSX-MUSIC builds. |
| 4 | Planar 48 KB | Serves the linear 48 KB style address range. |
| 5 | ASCII8 | Uses 8 KB ASCII bank registers. |
| 6 | ASCII16 | Uses 16 KB ASCII bank registers. |
| 7 | Konami | Uses Konami 8 KB bank registers. |
| 8 | NEO8 | Uses six 8 KB NEO bank registers. |
| 9 | NEO16 | Uses three 16 KB NEO bank registers. |
| 12 | ASCII16-X | Uses the ASCII16-X bank register layout for mirrored 16 KB pages. |
| 13 | Planar 64 KB | Serves the full 64 KB address space linearly. |
| 14 | Manbow2 | Not supported for FM-PAC/MSX-MUSIC builds. |

For unmapped subslots or unsupported windows, reads return `0xFF`.

---

## Access flow examples

### Direct YM2413 write

1. Z80 writes to I/O port `0x7C` or `0x7D`.
2. PIO1 captures the I/O write.
3. Core 1 drains the I/O FIFO while generating audio.
4. `msx_music_write_io()` forwards the write to emu2413.
5. Core 1 continues producing PCM samples for the I2S DAC.

### FM-PAC BIOS call path

1. Game calls MSX-MUSIC BIOS routines.
2. The MSX slot selection targets the FM-PAC subslot for the BIOS page.
3. Firmware reads bytes from the embedded `FMPCCMFC.BIN` image.
4. BIOS code writes FM-PAC OPLL registers at `0x7FF4` / `0x7FF5`, or direct ports depending on the routine.
5. Firmware forwards those writes to the same emu2413 OPLL instance.

### Game mapper access

1. Game selects the primary game subslot for its cartridge pages.
2. Firmware routes reads and mapper writes to the selected mapper implementation.
3. The game ROM continues to run from its normal mapper while the FM-PAC BIOS remains available from subslot 3.

---

## Compatibility notes

- `-f` and `-fmpac` are synonyms in the LoadROM tool.
- The feature is currently implemented for RP2350 LoadROM (`2350/software/loadrom.pio`).
- The FM-PAC BIOS is embedded into every `-f` / `-fmpac` non-SYSTEM external ROM UF2.
- ROMs that directly write YM2413 ports `0x7C`/`0x7D` are supported.
- ROMs that rely on MSX-MUSIC BIOS calls are supported by the embedded FM-PAC BIOS exposure.
- ROMs that use FM-PAC memory-mapped OPLL registers `0x7FF4`/`0x7FF5` are routed to the same YM2413 emulator.
- Konami SCC and Manbow2 mapper ROMs are rejected for FM-PAC/MSX-MUSIC builds.
- Audio is generated by the PicoVerse I2S DAC, not by the host MSX audio circuit.

---

## Limitations

- Only one Pico-side cartridge audio engine is active per UF2 image. MSX-MUSIC cannot be combined with SCC, SCC+, or Dual PSG in the same image.
- FM-PAC/MSX-MUSIC is not enabled for embedded Sunrise/Carnivore2 system modes.
- PAC SRAM is volatile. It is modeled in RAM and is not persisted across power cycles.
- The FM-PAC BIOS payload is an embedded third-party BIOS binary; distribution and use must respect the rights of the BIOS copyright holders.
- The implementation models the FM-PAC BIOS/register behavior needed by LoadROM titles, not a complete standalone FM-PAC cartridge with persistent SRAM management.

---

## Validation performed

The implementation was validated with the LoadROM build flow:

```
make firmware
make tool
```

The tool was also checked with an R-Type build:

```
loadrom.exe -fmpac -o rtype_fmpac.uf2 "R-Type - IREM.rom"
```

The generated output reported ASCII8 mapper detection, MSX-MUSIC/FM-PAC enablement with BIOS and ports `0x7C`/`0x7D`, and a larger UF2 due to the appended 64 KB BIOS payload.

Invalid combinations were checked to ensure the option rules still reject mutually exclusive audio modes and SYSTEM builds.

---

## Credits

- YM2413/OPLL emulation uses emu2413 by Mitsutaka Okazaki, licensed under the MIT License.
- `FMPCCMFC.BIN` is the English FM-PAC BIOS. The FM-PAC BIOS ROM is copyrighted by Matsushita Corp.; the English translation is credited to 232, Max Iwamoto, and GDX.

---

Author: Cristiano Almeida Goncalves

Last updated: 05/17/2026

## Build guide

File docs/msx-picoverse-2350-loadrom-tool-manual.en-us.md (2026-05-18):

# MSX PicoVerse 2350 LoadROM Tool Manual (EN-US)

The PicoVerse 2350 cartridge can boot either a MultiROM menu or a single ROM that starts immediately. The LoadROM tool creates a UF2 image that flashes the PicoVerse 2350 with a single ROM payload and the LoadROM firmware.

`loadrom.exe` bundles the Pico firmware blob, a configuration record (game name, mapper code, ROM size, and flash offset), and one MSX ROM file into an RP2350-compatible UF2 image. Copy the generated UF2 to the board in BOOTSEL mode and the MSX will boot straight into the embedded ROM.

For RP2350, the current LoadROM package is:

- `2350/software/loadrom.pio`.

> **Important:** SCC/SCC+ emulation options (`-scc`, `-sccplus`), the secondary AY-3-8910 dual PSG option (`-d`), and the MSX-MUSIC/YM2413 option (`-f` or `-fmpac`) are supported by the current RP2350 LoadROM package (`2350/software/loadrom.pio`). Exactly one on-cartridge audio mode can be active per UF2 image.

---

## Overview

1. **Input**: one `.ROM` file (case-insensitive extension).
2. **Processing**: the tool normalizes the ROM name, detects or forces the mapper, and streams firmware + config + ROM into UF2 blocks.
3. **Output**: a UF2 file (default `loadrom.uf2`) ready for the RP2350 bootloader.

Key characteristics:

- Windows console application.
- Supports ROM sizes from 8 KB up to 16 MB (subject to flash capacity).
- Mapper auto-detection plus optional filename tags to force the mapper.
- Embedded SHA-1 database derived from openMSX `softwaredb.xml` for improved mapper identification.
- Built-in Sunrise IDE Nextor ROM for standalone Nextor boot or Nextor + 1MB PSRAM mapper, using either the on-board microSD card (`-s1`/`-m1`) or a USB flash drive (`-s2`/`-m2`).
- Optional ESP-01 WiFi support for those Sunrise IDE modes via `-w`, adding an embedded ESP8266P system ROM and memio UART backend.
- ROM loading into the 1MB PSRAM mapper through Carnivore2-compatible RAM emulation for `SROM.COM /D15`, using either microSD (`-c1`) or USB mass storage (`-c2`) as the Nextor backend.
- UF2 uses RP2350 family ID (`0xE48BFF59`).

---

## Command-line usage

```
loadrom.exe [options] [romfile]
```

### Options

- `-h`, `--help` : Print usage information and exit.
- `-s1`, `--sunrise-sd` : Build a UF2 with the embedded Sunrise IDE Nextor ROM using the on-board microSD card slot for storage. No external ROM file is needed.
- `-m1`, `--mapper-sd` : Same as `-s1` plus a 1MB memory mapper (64 × 16KB pages) backed by external PSRAM on GPIO47 / QMI CS1 in an expanded sub-slot architecture. No external ROM file is needed.
- `-s2`, `--sunrise-usb` : Build a UF2 with the embedded Sunrise IDE Nextor ROM using the cartridge's USB-C port for storage (USB mass storage). No external ROM file is needed.
- `-m2`, `--mapper-usb` : Same as `-s2` plus a 1MB memory mapper (64 × 16KB pages) backed by external PSRAM on GPIO47 / QMI CS1 in an expanded sub-slot architecture. No external ROM file is needed.
- `-c1`, `--carnivore2-sd` : Build a UF2 with Sunrise IDE Nextor on microSD plus the 1MB PSRAM mapper and Carnivore2 RAM-mode emulation for `SROM.COM /D15`. In this mode, `SROM.COM` can upload a ROM image into the PSRAM-backed mapper and launch it from RAM without reflashing the cartridge.
- `-c2`, `--carnivore2-usb` : Same as `-c1`, but uses USB mass storage on the cartridge's USB-C port as the Nextor backend.
- `-w`, `--wifi` : Enable ESP-01 WiFi support for `-s1`, `-m1`, `-s2`, or `-m2`. This adds the ESP8266P system ROM plus a memory-mapped UART backend expected by the WiFi ROM/software stack.
- `-scc`, `--scc` : Enable SCC (standard) sound emulation. For embedded ROM builds, this applies to Konami SCC or Manbow2 mapper ROMs. With `-c1` or `-c2`, it enables SCC playback for Konami SCC ROMs uploaded later through `SROM.COM /D15`.
- `-sccplus`, `--sccplus` : Enable SCC+ (enhanced) sound emulation. For embedded ROM builds, this applies to Konami SCC or Manbow2 mapper ROMs. With `-c1` or `-c2`, it enables SCC+ playback for compatible ROMs uploaded later through `SROM.COM /D15`.
- `-d`, `--dual-psg` : Enable secondary AY-3-8910 (PSG) emulation on I/O ports `0x10` (register select) and `0x11` (data). The Pico captures `OUT (0x10/0x11),A` writes via PIO1 and streams a mixed signal to the I2S DAC alongside the host MSX's PSG. Only valid with external ROM files whose mapper is not Konami SCC or Manbow2 (those mappers carry an on-cartridge SCC chip and reserve the second audio slot for SCC emulation).
- `-f`, `-fmpac` : Enable MSX-MUSIC / YM2413 emulation on I/O ports `0x7C` (register select) and `0x7D` (data). The Pico captures OPLL writes via PIO1 and streams the generated FM audio to the I2S DAC. The UF2 also embeds the FM-PAC BIOS and exposes it in an expanded FM-PAC subslot so ROMs that use MSX-MUSIC BIOS calls can find it. Only valid with non-SYSTEM external ROM files.
- `-o <filename>`, `--output <filename>` : Override the UF2 output name (default `loadrom.uf2`).
- Positional argument: the ROM file to embed. Required for normal ROM loading; not accepted with `-s1`/`-m1`/`-s2`/`-m2`/`-c1`/`-c2`.

`-s1`, `-m1`, `-s2`, `-m2`, `-c1`, and `-c2` are mutually exclusive. `-w` is valid only with `-s1`, `-m1`, `-s2`, or `-m2`. The audio options `-scc`, `-sccplus`, `-d`, and `-f`/`-fmpac` are mutually exclusive — only one on-cartridge audio engine can be active per UF2 image. `-d` is additionally rejected for Konami SCC and Manbow2 ROMs, while `-d` and `-f`/`-fmpac` are rejected for the embedded Sunrise/Carnivore2 system modes. `-f`/`-fmpac` is also rejected for Konami SCC and Manbow2 mapper ROMs. If conflicting options are provided, the tool exits with an error.

For the firmware architecture behind `-d`, see the [PicoVerse 2350 Dual PSG implementation guide](./msx-picoverse-2350-dualpsg.md).

When `-f` or `-fmpac` is selected, LoadROM keeps the selected game mapper active and adds the FM-PAC BIOS/register area in the cartridge's expanded slot layout. The Pico responds to both direct YM2413 I/O writes and FM-PAC memory-mapped register writes at `0x7FF4`/`0x7FF5`.

For the firmware architecture behind `-f` / `-fmpac`, see the [PicoVerse 2350 MSX-MUSIC / FM-PAC implementation guide](./msx-picoverse-2350-fmpac.md).

### Mapper forcing via filename tags

Append a dot-separated mapper tag before the `.ROM` extension to override detection. Tags are case-insensitive.

Supported tags:
`PLA-16`, `PLA-32`, `KonSCC`, `PLN-48`, `PLN-64`, `ASC-08`, `ASC-16`, `ASC-16X`, `Konami`, `NEO-8`, `NEO-16`, `MANBW2`.

Additional aliases are accepted for backward compatibility: `PL-16`, `PL-32`, `PL-48`, `PL-64`, `PLN-32`, `PLANAR`, `LINEAR`, `LINEAR0`, `PLANAR48`, `PLANAR64`, `MANBOW2`, `MBW-2`.

Example:

```
Penguin Adventure.PL-32.ROM
Space Manbow.KonSCC.rom
```

Tags are case-insensitive. If no valid tag is present, the tool first computes the ROM's SHA-1 hash and looks it up in an embedded database derived from the openMSX `softwaredb.xml`. When a match is found the database mapper type is used directly. Otherwise the tool falls back to heuristic detection.

`SYSTEM` is ignored and cannot be forced.

---

## Typical workflow

1. Place `loadrom.exe` and your ROM file in a working folder.
2. Open a Command Prompt or PowerShell window in that folder.
3. Run the tool:
   ```
   loadrom.exe "Space Manbow.rom" -o space_manbow.uf2
   ```
   Sunrise IDE standalone (Nextor from microSD card):
   ```
   loadrom.exe -s1
   loadrom.exe -s1 -o nextor_sd.uf2
   ```
   Sunrise IDE standalone with WiFi (microSD):
   ```
   loadrom.exe -s1 -w
   loadrom.exe -s1 -w -o nextor_sd_wifi.uf2
   ```
   Sunrise IDE + 1MB PSRAM mapper (microSD):
   ```
   loadrom.exe -m1
   loadrom.exe -m1 -o nextor_mapper_sd.uf2
   ```
   Sunrise IDE + 1MB PSRAM mapper with WiFi (microSD):
   ```
   loadrom.exe -m1 -w
   loadrom.exe -m1 -w -o nextor_mapper_sd_wifi.uf2
   ```
   Sunrise IDE standalone (Nextor from USB flash drive):
   ```
   loadrom.exe -s2
   loadrom.exe -s2 -o nextor_usb.uf2
   ```
   Sunrise IDE standalone with WiFi (USB):
   ```
   loadrom.exe -s2 -w
   loadrom.exe -s2 -w -o nextor_usb_wifi.uf2
   ```
   Sunrise IDE + 1MB PSRAM mapper (USB):
   ```
   loadrom.exe -m2
   loadrom.exe -m2 -o nextor_mapper_usb.uf2
   ```
   Sunrise IDE + 1MB PSRAM mapper with WiFi (USB):
   ```
   loadrom.exe -m2 -w
   loadrom.exe -m2 -w -o nextor_mapper_usb_wifi.uf2
   ```
   Carnivore2 RAM-mode loader for `SROM.COM /D15` (microSD):
   ```
   loadrom.exe -c1
   loadrom.exe -c1 -o srom_c2_sd.uf2
   ```
   Carnivore2 RAM-mode loader for `SROM.COM /D15` (USB):
   ```
   loadrom.exe -c2
   loadrom.exe -c2 -o srom_c2_usb.uf2
   ```
   Carnivore2 RAM-mode loader with SCC audio for SROM-loaded Konami SCC ROMs:
   ```
   loadrom.exe -c1 -scc -o srom_c2_sd_scc.uf2
   loadrom.exe -c2 -scc -o srom_c2_usb_scc.uf2
   ```
   SCC/SCC+ examples:
   ```
   loadrom.exe -scc "Space Manbow.rom"
   loadrom.exe -sccplus "Snatcher.KonSCC.rom"
   ```
   Dual PSG example (secondary AY-3-8910 on ports `0x10`/`0x11`):
   ```
   loadrom.exe -d "Penguin Adventure - 2 x PSG - Darky.rom"
   ```
   MSX-MUSIC example (YM2413 on ports `0x7C`/`0x7D`):
   ```
   loadrom.exe -f "Game with MSX-MUSIC.rom"
   loadrom.exe -fmpac "Game with FM music.rom"
   ```
4. Review the console output (name, size, mapper, and flash offset).
5. Hold BOOTSEL while connecting the PicoVerse 2350 to USB.
6. Copy the generated UF2 to the `RPI-RP2` drive.
7. Insert the cartridge into the MSX and power on.
8. For `-s1`/`-m1` modes, insert a FAT-formatted microSD card into the cartridge's microSD slot before powering the MSX.
9. For `-s2`/`-m2` modes, connect a USB flash drive (via OTG adapter if needed) to the cartridge's USB-C port before powering the MSX.
10. For `-w` builds, install the ESP-01 module on the PicoVerse 2350 before power-up. The WiFi system ROM and memio UART interface are then available to compatible MSX software.
11. For `-c1`/`-c2` modes, boot Nextor first and then use `SROM.COM /D15` to upload the ROM into the PicoVerse PSRAM mapper. The cartridge is presented as a Carnivore2-compatible RAM target so the uploaded ROM can be launched directly from RAM.

---

## Output layout details

The UF2 image contains:

1. **Firmware blob** – embedded `loadrom` firmware.
2. **Configuration record** (59 bytes):
   - 50 bytes: ROM name (ASCII, padded/truncated).
   - 1 byte : mapper ID plus optional audio/WiFi flags:
     - Bit 7 (`0x80`) = SCC emulation enabled.
     - Bit 6 (`0x40`) = SCC+ emulation enabled.
   - Bit 5 (`0x20`) = WiFi support enabled for Sunrise IDE modes, or MSX-MUSIC/YM2413 enabled for non-SYSTEM ROMs.
     - Bit 4 (`0x10`) = Dual PSG emulation enabled (secondary AY-3-8910 on ports `0x10`/`0x11`).
     - Bits 0..3 = base mapper ID.
   - 4 bytes: ROM size (little-endian).
   - 4 bytes: ROM flash offset (little-endian).
3. **ROM payload** – raw ROM data appended after the config record.

The UF2 writer sets `UF2_FLAG_FAMILYID_PRESENT` and uses the RP2350 family ID (`0xE48BFF59`) so the bootloader accepts the image.

---

## Troubleshooting

| Symptom | Possible cause | Resolution |
| --- | --- | --- |
| "Invalid ROM size" | ROM < 8 KB or > 16 MB | Use a valid ROM size. |
| "Failed to detect the ROM type" | Mapper heuristics failed | Add a mapper tag (e.g., `.Konami.ROM`). |
| "Sunrise options are mutually exclusive" | More than one of `-s1`/`-m1`/`-s2`/`-m2`/`-c1`/`-c2` passed | Use only one firmware mode at a time. The `-m` variants add mapper RAM; the `-c` variants add Carnivore2 RAM-mode loading on top of the mapper architecture. |
| "Sunrise options do not accept an external ROM file" | ROM file passed with a Sunrise/Carnivore2 option | Remove the ROM file argument when using `-s1`/`-m1`/`-s2`/`-m2`/`-c1`/`-c2`. |
| "Error: -w/--wifi is supported only with -s1, -m1, -s2 or -m2" | `-w` was used without a supported Sunrise mode | Pair `-w` only with `-s1`, `-m1`, `-s2`, or `-m2`. |
| USB pendrive not detected with `-s2`/`-m2` | VBUS not connected or no OTG adapter | Ensure the USB-C port has VBUS power (use an OTG adapter that supplies VBUS). |
| microSD card not detected with `-s1`/`-m1` | Card not inserted or not FAT-formatted | Insert a FAT16/FAT32-formatted microSD card before powering on. |
| WiFi software does not detect the adapter with `-w` | Missing ESP-01 module, incompatible ESP firmware, or wrong WiFi-capable UF2 | Reflash a `-w` build, verify the ESP-01 is installed, and use software targeting the ESP8266P memio interface. |
| `SROM.COM /D15` does not list the cartridge with `-c1`/`-c2` | Wrong firmware mode or outdated build | Reflash with the correct `-c1` or `-c2` UF2 and use a build that includes Carnivore2 RAM-mode emulation. |
| `SROM.COM /D15` upload succeeds but the launched ROM fails | ROM/runtime compatibility issue in the emulation path | Try the latest firmware build and retest; this mode depends on Carnivore2-compatible bank/window presentation from PSRAM. |
| "Disk driver not found. System halted." with `-m1`/`-m2` | Firmware issue | Rebuild with latest firmware; check that the PIO bus init guard is present. |
| "Warning: -scc flag ignored" | ROM is not Konami SCC or Manbow2 mapper, or the selected Nextor mode is not `-c1`/`-c2` | Use a Konami SCC or Manbow2 ROM, or pair `-scc` with `-c1`/`-c2` for SROM-loaded Konami SCC titles. |
| "Warning: -sccplus flag ignored" | ROM is not Konami SCC or Manbow2 mapper, or the selected Nextor mode is not `-c1`/`-c2` | Use a compatible ROM, or pair `-sccplus` with `-c1`/`-c2` for SROM-loaded SCC+ titles. |
| "Error: -scc and -sccplus are mutually exclusive" | Both options were passed together | Use only one of the two options. |
| UF2 not recognized | Not in BOOTSEL, or wrong file | Enter BOOTSEL and copy the UF2 again. |
| Name truncated in menu | Filename too long | Shorten the filename. |

---

## Known limitations

- Only one ROM per UF2 (use the MultiROM or Explorer tools for multiple titles).
- The `-s1` and `-m1` options require a FAT-formatted microSD card in the cartridge's microSD slot.
- The `-s2` and `-m2` options require a USB flash drive connected to the cartridge's USB-C port (via OTG adapter) for disk access.
- The `-w` option is available only with `-s1`, `-m1`, `-s2`, or `-m2`.
- `-w` requires an ESP-01 module and compatible ESP-side firmware; the PicoVerse firmware provides the ROM mapping and serial transport, not the ESP application layer itself.
- The `-m1` and `-m2` options provide 1MB mapper RAM (64 × 16KB pages) backed by external PSRAM on GPIO47 / QMI CS1.
- The `-c1` and `-c2` options reuse that same 1MB PSRAM-backed mapper RAM and expose it through Carnivore2-compatible RAM-mode behavior intended for `SROM.COM /D15`.
- The `-w` Sunrise IDE WiFi system-ROM option is not currently exposed in Explorer or the `-c1`/`-c2` Carnivore2 loader modes. MultiROM supports `-w` for `-s1`, `-m1`, `-s2`, and `-m2` Nextor entries. Explorer has its own built-in ESP-01 path for File Hunter browsing and WiFi setup.
- The `-c1` and `-c2` modes are loader modes, not direct ROM-embedding modes. They boot Nextor first; the ROM is uploaded later from DOS into PSRAM.
- SCC/SCC+ audio for `SROM.COM /D15` uploads is enabled by building the loader UF2 with `-c1/-c2` plus `-scc` or `-sccplus` before flashing the cartridge.
- Linux/macOS binaries are not provided (use Windows or build from source).
- The tool does not verify ROM integrity beyond size and mapper heuristics.
- SCC/SCC+ flags are applied for Konami SCC mapper (type 3) and Manbow2 mapper (type 14) ROMs; otherwise they are ignored with a warning.
- SCC/SCC+ emulation is available in the current RP2350 LoadROM package.
- Excessive flashing can wear out flash memory.

---

## Future improvements

- Cross-platform builds (Linux/macOS).
- Optional ROM integrity checks.
- GUI wrapper for mapper forcing.
- Additional mapper heuristics.

Author: Cristiano Almeida Goncalves  
Last updated: 04/21/2026

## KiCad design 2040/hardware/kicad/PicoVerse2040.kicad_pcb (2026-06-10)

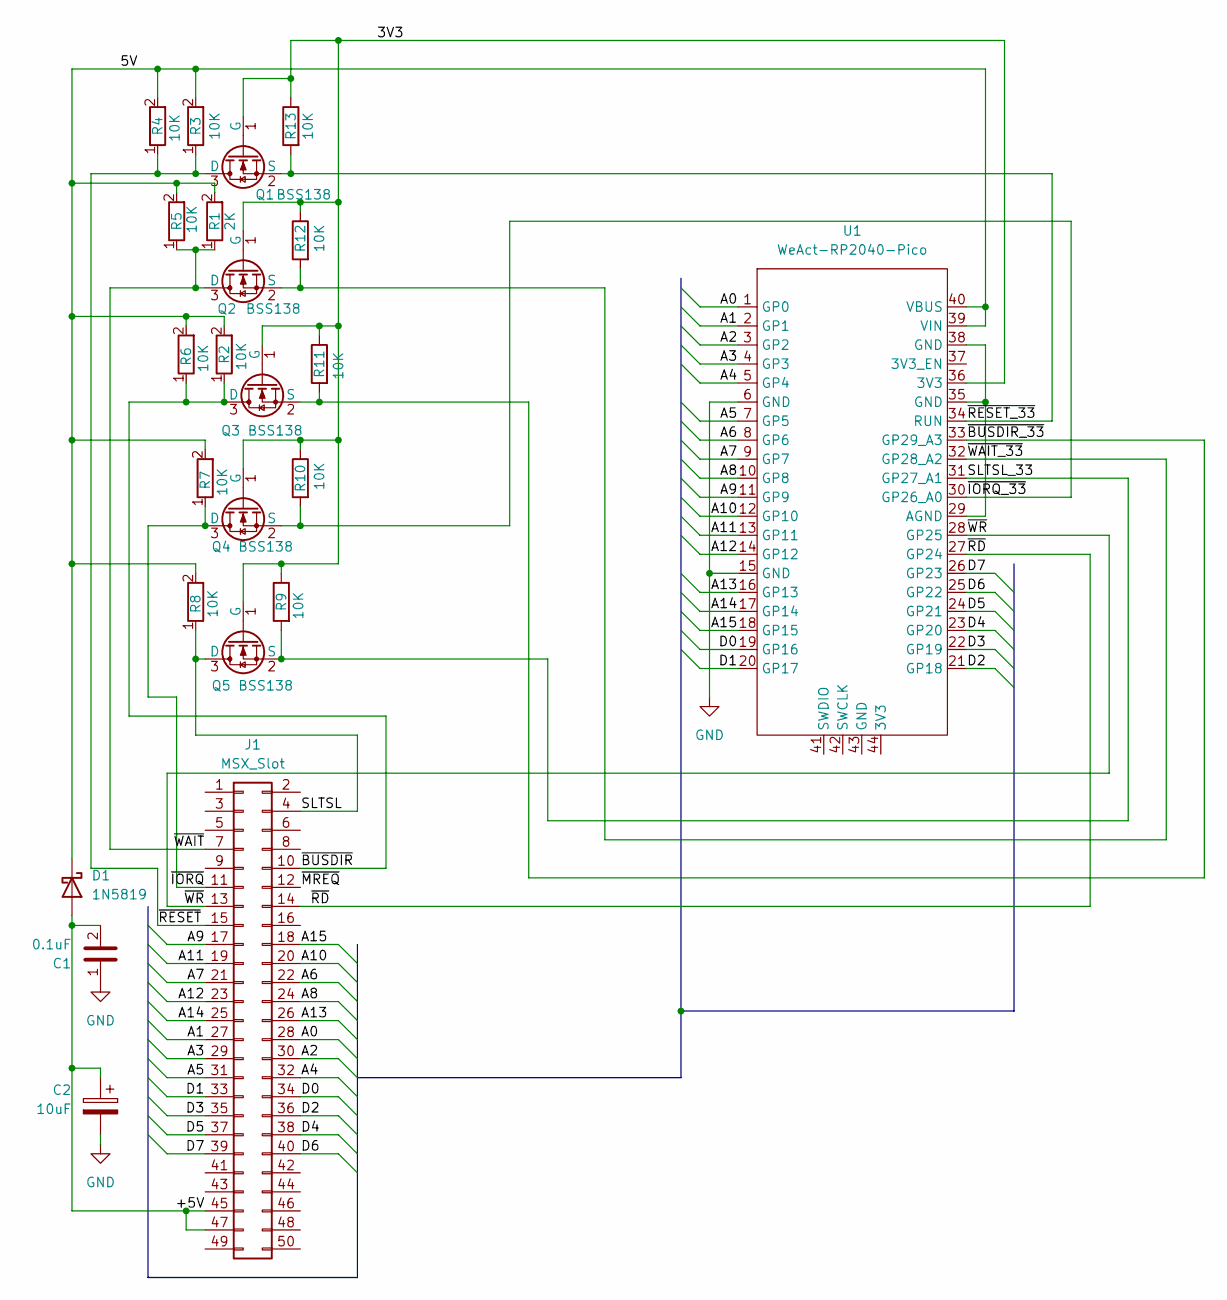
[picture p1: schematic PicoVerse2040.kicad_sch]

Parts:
C1: 0.1uF; C_0603_1608Metric_Pad1.08x0.95mm_HandSolder
C2: 10uF; C_0603_1608Metric_Pad1.08x0.95mm_HandSolder
D1: 1N5819; D_SOD-123
J1: MSX_Slot
Q1, Q2, Q3, Q4, Q5: BSS138; SOT-23
R1: 2K; R_0603_1608Metric
R2, R3, R4, R5, R6, R7, R8, R9, R10, R11, R12, R13: 10K; R_0603_1608Metric_Pad0.98x0.95mm_HandSolder
U1: WeAct-RP2040-Pico; RaspberryPi_Pico_Common_THT

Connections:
/3V3: Q1.1 (G), Q2.1 (G), Q3.1 (G), Q4.1 (G), Q5.1 (G), R9.1, R10.1, R11.1, R12.1, R13.1, U1.36 (3V3)
/5V: D1.1 (K), R1.2, R2.2, R3.2, R4.2, R5.2, R6.2, R7.2, R8.2, U1.39 (VIN), U1.40 (VBUS)
/+5V: C1.2, C2.1, D1.2 (A), J1.45, J1.47
/A0: J1.28, U1.1 (GP0)
/A1: J1.27, U1.2 (GP1)
/A2: J1.30, U1.3 (GP2)
/A3: J1.29, U1.4 (GP3)
/A4: J1.32, U1.5 (GP4)
/A5: J1.31, U1.7 (GP5)
/A6: J1.22, U1.8 (GP6)
/A7: J1.21, U1.9 (GP7)
/A8: J1.24, U1.10 (GP8)
/A9: J1.17, U1.11 (GP9)
/A10: J1.20, U1.12 (GP10)
/A11: J1.19, U1.13 (GP11)
/A12: J1.23, U1.14 (GP12)
/A13: J1.26, U1.16 (GP13)
/A14: J1.25, U1.17 (GP14)
/A15: J1.18, U1.18 (GP15)
/D0: J1.34, U1.19 (GP16)
/D1: J1.33, U1.20 (GP17)
/D2: J1.36, U1.21 (GP18)
/D3: J1.35, U1.22 (GP19)
/D4: J1.38, U1.23 (GP20)
/D5: J1.37, U1.24 (GP21)
/D6: J1.40, U1.25 (GP22)
/D7: J1.39, U1.26 (GP23)
/SLTSL: J1.4, Q5.3 (D), R8.1
/SLTSL_33: Q5.2 (S), R9.2, U1.31 (GP27_A1)
/~BUSDIR_33: Q3.2 (S), R11.2, U1.33 (GP29_A3)
/~BUSDIR: J1.10, Q3.3 (D), R2.1, R6.1
/~IORQ_33: Q4.2 (S), R10.2, U1.30 (GP26_A0)
/~IORQ: J1.11, Q4.3 (D), R7.1
/~RD: J1.14, U1.27 (GP24)
/~RESET_33: Q1.2 (S), R13.2, U1.34 (RUN)
/~RESET: J1.15, Q1.3 (D), R3.1, R4.1
/~WAIT_33: Q2.2 (S), R12.2, U1.32 (GP28_A2)
/~WAIT: J1.7, Q2.3 (D), R1.1, R5.1
/~WR: J1.13, U1.28 (GP25)
GND: C1.1, C2.2, U1.6 (GND), U1.15 (GND)
unnamed: U1.29 (AGND), U1.35 (GND), U1.38 (GND)

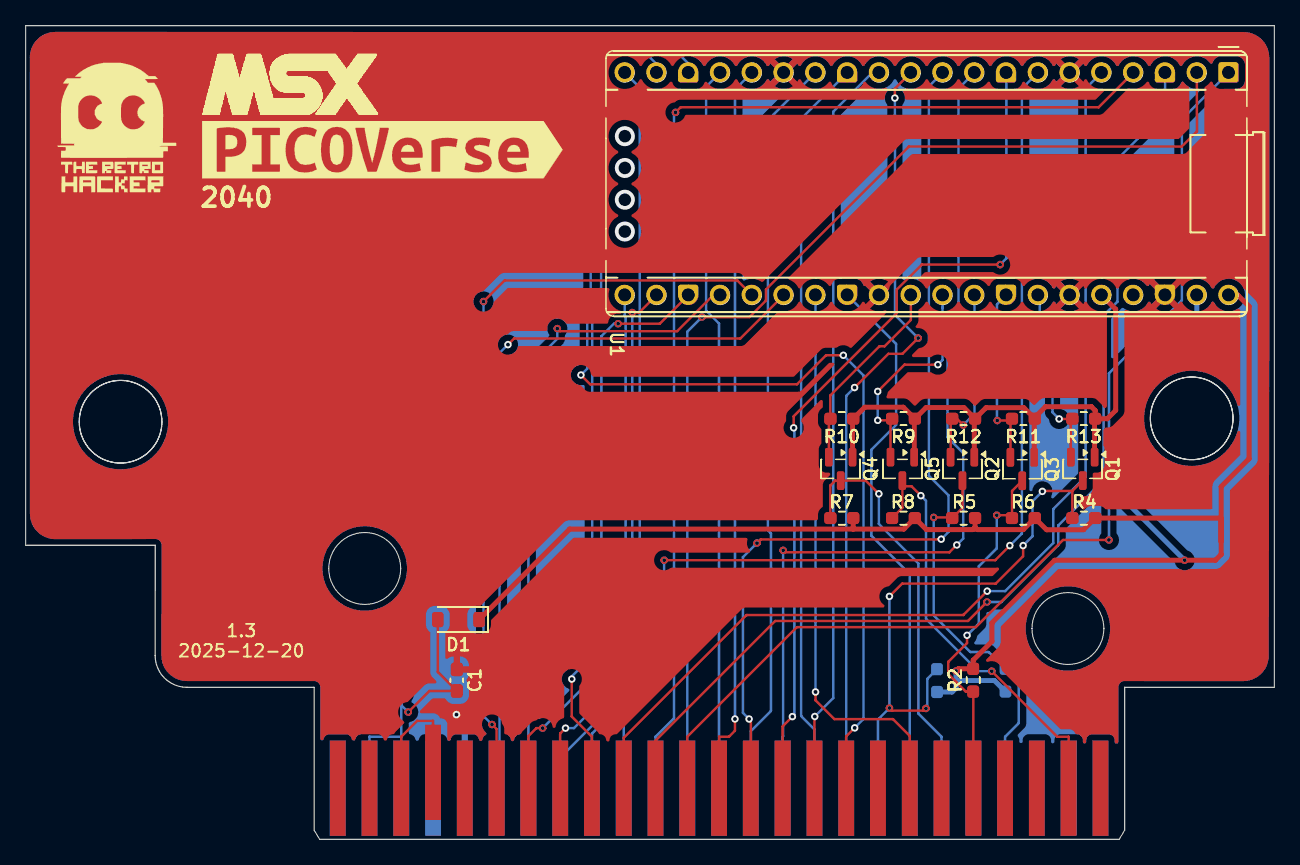
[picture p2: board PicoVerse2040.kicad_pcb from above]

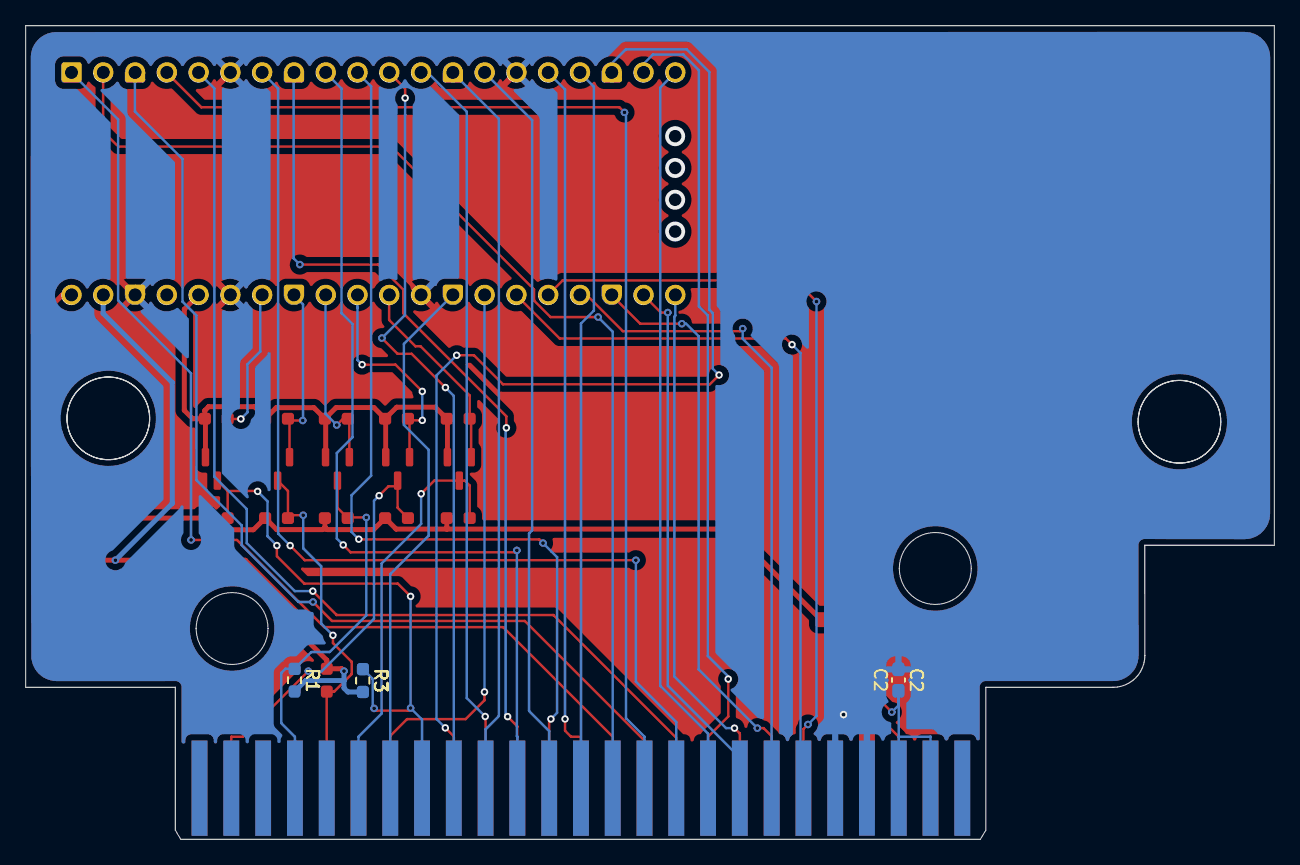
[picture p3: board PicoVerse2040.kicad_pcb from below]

Board: 2 copper layers, 99.8 x 65.0 mm, 22 parts (3 on the bottom side), 15 nets.

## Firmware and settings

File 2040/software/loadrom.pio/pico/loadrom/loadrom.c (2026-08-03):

// MSX PICOVERSE PROJECT
// (c) 2026 Cristiano Goncalves
// The Retro Hacker
//
// loadrom.c - PIO-based ROM loader for MSX PICOVERSE project - v2.0
//
// This program loads ROM images using the MSX PICOVERSE project with the RP2040 PIO
// (Programmable I/O) hardware to handle MSX bus timing deterministically.
// The PIO state machines monitor /SLTSL and /RD//WR signals, assert /WAIT to freeze
// the Z80, and exchange address/data with the CPU through FIFOs. This frees the CPU
// from tight bit-banging loops and guarantees timing via the /WAIT mechanism.
//
// You need to concatenate the ROM image to the end of this program binary in order to load it.
// The program will then act as a simple ROM cartridge that responds to memory read requests from the MSX.
// 
// This work is licensed under a "Creative Commons Attribution-NonCommercial-ShareAlike 4.0 International
// License". https://creativecommons.org/licenses/by-nc-sa/4.0/

#include <string.h>
#include "pico/stdlib.h"
#include "pico/multicore.h"
#include "hardware/clocks.h"
#include "hardware/dma.h"
#include "hardware/pio.h"
#include "hardware/sync.h"
#include "../../tool/src/nextor_sunrise.h"
#include "loadrom.h"
#include "sunrise_ide.h"
#define MUX_ADDR
#ifdef MUX_ADDR
#include "msx_bus2.pio.h"
#else
#include "msx_bus.pio.h"
#endif
#include "loop.h"
#include "tusb_config.h"
#include "tusb.h"
#ifdef MUX_ADDR
#include "sunrise_sd.h"
#endif
// -----------------------------------------------------------------------
// PIO bus context
// -----------------------------------------------------------------------
typedef struct {
    PIO pio_read;
    PIO pio_write;
    PIO pio_bus;
    uint sm_read;
    uint sm_write;
    uint sm_bus_writer;
    int offset_read;
    int offset_write;
    int offset_bus;
} msx_pio_bus_t;

static msx_pio_bus_t msx_bus;
static uint32_t rom_cached_size = 0;
static bool msx_bus_programs_loaded = false;

static msx_pio_bus_t msx_io_bus;
static bool msx_io_bus_programs_loaded = false;

// Current cache capacity in bytes. Normal mode uses full rom_sram size,
// mapper mode reduces this to 0 so mapper RAM can use full SRAM.
static uint32_t rom_cache_capacity = CACHE_SIZE;

// -----------------------------------------------------------------------
// ROM source preparation (cache to SRAM, flash fallback for large ROMs)
// -----------------------------------------------------------------------
// For ROMs that fit in the 192KB SRAM cache, the entire ROM is copied to
// SRAM and rom_base is redirected there.  For ROMs larger than the cache,
// the first 192KB is cached in SRAM and rom_base stays pointing to flash.
// read_rom_byte() transparently serves from SRAM for offsets within the
// cached region and falls back to flash XIP for the rest.
static inline void __not_in_flash_func(prepare_rom_source)(
    uint32_t offset,
    bool cache_enable,
    uint32_t preferred_size,
    const uint8_t **rom_base_out,
    uint32_t *available_length_out)
{
    const uint8_t *rom_base = rom + offset;
    uint32_t available_length = active_rom_size;

    if (preferred_size != 0u && (available_length == 0u || available_length > preferred_size))
    {
        available_length = preferred_size;
    }

    if (cache_enable && available_length > 0u)
    {
        uint32_t bytes_to_cache = (available_length > rom_cache_capacity)
                      ? rom_cache_capacity
                                  : available_length;

        gpio_init(PIN_WAIT);
        gpio_set_dir(PIN_WAIT, GPIO_OUT);
        gpio_put(PIN_WAIT, 0);

        // DMA bulk copy from flash XIP to SRAM.
        // Byte transfers are used because rom_base may not be 4-byte aligned
        // (ROM data starts at __flash_binary_end + 55-byte header).  With
        // DMA_SIZE_32 the RP2040 silently masks the two LSBs of the address,
        // reading from the wrong location and corrupting the cache.
        int dma_chan = dma_claim_unused_channel(true);
        dma_channel_config dma_cfg = dma_channel_get_default_config(dma_chan);
        channel_config_set_transfer_data_size(&dma_cfg, DMA_SIZE_8);
        channel_config_set_read_increment(&dma_cfg, true);
        channel_config_set_write_increment(&dma_cfg, true);
        dma_channel_configure(dma_chan, &dma_cfg,
            rom_sram,                        // write address (SRAM)
            rom_base,                        // read address (flash XIP)
            bytes_to_cache,                  // transfer count (bytes)
            true);                           // start immediately
        dma_channel_wait_for_finish_blocking(dma_chan);
        dma_channel_unclaim(dma_chan);
        gpio_set_dir(PIN_WAIT, GPIO_IN);

        rom_cached_size = bytes_to_cache;

        if (available_length <= rom_cache_capacity)
        {
            // Entire ROM fits in SRAM cache
            rom_base = rom_sram;
        }
        // else: ROM exceeds cache.  rom_base stays pointing to flash.
        // read_rom_byte() serves from SRAM for offsets < rom_cached_size,
        // and falls back to flash XIP for the rest.
    }
    else
    {
        rom_cached_size = 0;
    }

    *rom_base_out = rom_base;
    *available_length_out = available_length;
}

// -----------------------------------------------------------------------
// GPIO initialisation (address, data, control pins)
// -----------------------------------------------------------------------
static inline void setup_gpio(void)
{
    // Address pins A0-A15 as inputs
    for (uint pin = PIN_A0; pin <= PIN_A15; ++pin)
    {
        gpio_init(pin);
        gpio_set_dir(pin, GPIO_IN);
    }
#ifdef MUX_ADDR
    gpio_init(PIN_A_HIGH); gpio_set_dir(PIN_A_HIGH, GPIO_OUT);
#endif
    // Data pins D0-D7 (will be managed by PIO)
    for (uint pin = PIN_D0; pin <= PIN_D7; ++pin)
    {
        gpio_init(pin);
    }

    // Control signals as inputs
    gpio_init(PIN_RD);      gpio_set_dir(PIN_RD, GPIO_IN);
    gpio_init(PIN_WR);      gpio_set_dir(PIN_WR, GPIO_IN);
    gpio_init(PIN_IORQ);    gpio_set_dir(PIN_IORQ, GPIO_IN);
    gpio_init(PIN_SLTSL);   gpio_set_dir(PIN_SLTSL, GPIO_IN);
    gpio_init(PIN_BUSDIR);  gpio_set_dir(PIN_BUSDIR, GPIO_IN);
}

static inline void reset_pio(PIO pio, uint sm)
{
    pio_sm_set_enabled(pio, sm, false);
    pio_sm_clear_fifos(pio, sm);
    pio_sm_restart(pio, sm);
}

static inline void put_bus_blocking(uint32_t token)
{
    //pio_sm_put_blocking(msx_bus.pio_read, msx_bus.sm_read, token);
    pio_sm_put_blocking(msx_bus.pio_bus, msx_bus.sm_bus_writer, token);
}

// -----------------------------------------------------------------------
// PIO bus initialisation
// -----------------------------------------------------------------------
static void msx_pio_bus_init(void)
{
    msx_bus.pio_read  = pio0;
    msx_bus.pio_bus   = pio0;
    msx_bus.pio_write = pio1;
    msx_bus.sm_read       = 0;
    msx_bus.sm_bus_writer = 1;
    msx_bus.sm_write      = 0;

    if (!msx_bus_programs_loaded)
    {
        if ((msx_bus.offset_read  = pio_add_program(msx_bus.pio_read, &msx_read_responder_program))<0)
            panic("Failed to add program");
        if ((msx_bus.offset_bus  = pio_add_program(msx_bus.pio_bus, &msx_bus_writer_program))<0)
            panic("Failed to add program");
        if ((msx_bus.offset_write = pio_add_program(msx_bus.pio_write, &msx_write_captor_program))<0)
            panic("Failed to add program");
        msx_bus_programs_loaded = true;
    }

    reset_pio(msx_bus.pio_read, msx_bus.sm_read);
    reset_pio(msx_bus.pio_bus, msx_bus.sm_bus_writer);
    reset_pio(msx_bus.pio_write, msx_bus.sm_write);
    pio_sm_exec(msx_bus.pio_bus, msx_bus.sm_bus_writer, pio_encode_jmp(msx_bus.offset_bus));

#ifdef MUX_ADDR
    pio_gpio_init(msx_bus.pio_read, PIN_A_HIGH);
    pio_gpio_init(msx_bus.pio_write, PIN_A_HIGH2);
    gpio_pull_down(PIN_A_HIGH);
    gpio_pull_down(PIN_A_HIGH2);
    gpio_set_drive_strength(PIN_A_HIGH, GPIO_DRIVE_STRENGTH_8MA);
    gpio_set_drive_strength(PIN_A_HIGH2, GPIO_DRIVE_STRENGTH_8MA);
    pio_sm_set_consecutive_pindirs(msx_bus.pio_read, msx_bus.sm_read, PIN_A_HIGH, 1, true);
    pio_sm_set_consecutive_pindirs(msx_bus.pio_write, msx_bus.sm_write, PIN_A_HIGH2, 1, true);
 
    pio_sm_set_pins_with_mask(msx_bus.pio_read, msx_bus.sm_read, 0/* (1 << PIN_A_HIGH) */, (1 << PIN_A_HIGH));
    pio_sm_set_pins_with_mask(msx_bus.pio_write, msx_bus.sm_write, 0/* (1 << PIN_A_HIGH) */, (1 << PIN_A_HIGH2));
#endif
    // ----- Read responder SM (SM0) -----
    pio_sm_config cfg_read = msx_read_responder_program_get_default_config(msx_bus.offset_read);
#ifdef MUX_ADDR    
    sm_config_set_in_pins(&cfg_read, PIN_A8);
#else
    sm_config_set_in_pins(&cfg_read, PIN_A0);
#endif
    sm_config_set_in_shift(&cfg_read, false, false, 16);
    //sm_config_set_out_pins(&cfg_read, PIN_D0, 8);
    sm_config_set_out_shift(&cfg_read, true, false, 32);
#ifdef MUX_ADDR    
    sm_config_set_set_pins(&cfg_read, PIN_A_HIGH, 1);
#endif
    //sm_config_set_set_pins(&cfg_read, PIN_WAIT, 1);
    sm_config_set_jmp_pin(&cfg_read, PIN_RD);
    sm_config_set_clkdiv(&cfg_read, 1.0f);
    pio_sm_init(msx_bus.pio_read, msx_bus.sm_read, msx_bus.offset_read, &cfg_read);


    // ----- Bus writer SM -----
    pio_sm_config cfg_bus = msx_bus_writer_program_get_default_config(msx_bus.offset_bus);
    sm_config_set_in_shift(&cfg_bus, false, false, 16);
    sm_config_set_out_pins(&cfg_bus, PIN_D0, 8);
    sm_config_set_out_shift(&cfg_bus, true, false, 32);
    sm_config_set_sideset_pin_base(&cfg_bus, PIN_WAIT);

    //sm_config_set_jmp_pin(&cfg_bus, PIN_RD);
    sm_config_set_clkdiv(&cfg_bus, 1.0f);
    pio_sm_init(msx_bus.pio_bus, msx_bus.sm_bus_writer, msx_bus.offset_bus, &cfg_bus);

    // Now hand /WAIT to PIO1 — the output register already has it HIGH
    pio_gpio_init(msx_bus.pio_bus, PIN_WAIT);
    pio_gpio_init(msx_bus.pio_bus, PIN_BUSDIR);
    pio_sm_set_consecutive_pindirs(msx_bus.pio_bus, msx_bus.sm_bus_writer, PIN_WAIT, 2, true);

    // Set /WAIT pin HIGH in the PIO output register BEFORE switching mux.
    // This prevents a brief /WAIT=LOW glitch that would freeze the Z80.
    pio_sm_set_pins_with_mask(msx_bus.pio_bus, msx_bus.sm_bus_writer, 1u << PIN_WAIT, 1u << PIN_WAIT);


    // ----- Write captor SM (SM1) -----
    pio_sm_config cfg_write = msx_write_captor_program_get_default_config(msx_bus.offset_write);
#ifdef MUX_ADDR    
    sm_config_set_in_pins(&cfg_write, PIN_A8);
#else
    sm_config_set_in_pins(&cfg_write, PIN_A0);
#endif
    sm_config_set_in_shift(&cfg_write, false, false, 32);
    sm_config_set_out_shift(&cfg_write, true, false, 32);
    sm_config_set_fifo_join(&cfg_write, PIO_FIFO_JOIN_RX);
    sm_config_set_jmp_pin(&cfg_write, PIN_WR);
#ifdef MUX_ADDR    
    sm_config_set_set_pins(&cfg_write, PIN_A_HIGH2, 1);
#endif
    sm_config_set_clkdiv(&cfg_write, 1.0f);
    pio_sm_init(msx_bus.pio_write, msx_bus.sm_write, msx_bus.offset_write, &cfg_write);

    pio_sm_set_consecutive_pindirs(msx_bus.pio_bus, msx_bus.sm_bus_writer, PIN_WAIT, 1, true);

    for (uint pin = PIN_D0; pin <= PIN_D7; ++pin)
    {
        pio_gpio_init(msx_bus.pio_bus, pin);
    }
    //pio_sm_set_consecutive_pindirs(msx_bus.pio_read, msx_bus.sm_read, PIN_D0, 8, false);
    pio_sm_set_consecutive_pindirs(msx_bus.pio_bus, msx_bus.sm_bus_writer, PIN_D0, 8, false);
    //pio_sm_set_consecutive_pindirs(msx_bus.pio_write, msx_bus.sm_write, PIN_D0, 8, false);

    pio_sm_set_enabled(msx_bus.pio_read, msx_bus.sm_read, true);
    pio_sm_set_enabled(msx_bus.pio_bus, msx_bus.sm_bus_writer, true);
    pio_sm_set_enabled(msx_bus.pio_write, msx_bus.sm_write, true);
}

// -----------------------------------------------------------------------
// PIO I/O bus initialisation (for memory mapper port access on PIO1)
// -----------------------------------------------------------------------
static void msx_pio_io_bus_init(void)
{
    msx_io_bus.pio_read  = pio0;
    msx_io_bus.pio_write = pio1;
    msx_io_bus.sm_read  = 2;
    msx_io_bus.sm_write = 1;

    if (!msx_io_bus_programs_loaded)
    {
        if ((msx_io_bus.offset_read = pio_add_program(msx_io_bus.pio_read, &msx_io_read_responder_program))<0)
            panic("Failed to add program");
        if ((msx_io_bus.offset_write = pio_add_program(msx_io_bus.pio_write, &msx_io_write_captor_program))<0)
            panic("Failed to add program");
        msx_io_bus_programs_loaded = true;
    }

    reset_pio(msx_io_bus.pio_read, msx_io_bus.sm_read);
    reset_pio(msx_io_bus.pio_write, msx_io_bus.sm_write);

#ifdef MUX_ADDR
    pio_gpio_init(msx_io_bus.pio_read, PIN_A_HIGH);
    pio_gpio_init(msx_io_bus.pio_write, PIN_A_HIGH2);
    gpio_pull_down(PIN_A_HIGH);
    gpio_pull_down(PIN_A_HIGH2);
    gpio_set_drive_strength(PIN_A_HIGH, GPIO_DRIVE_STRENGTH_8MA);
    gpio_set_drive_strength(PIN_A_HIGH2, GPIO_DRIVE_STRENGTH_8MA);
    pio_sm_set_consecutive_pindirs(msx_io_bus.pio_read, msx_io_bus.sm_read, PIN_A_HIGH, 1, true);
    pio_sm_set_consecutive_pindirs(msx_io_bus.pio_write, msx_io_bus.sm_write, PIN_A_HIGH2, 1, true);
 
    pio_sm_set_pins_with_mask(msx_io_bus.pio_read, msx_io_bus.sm_read, 0/* (1 << PIN_A_HIGH) */, (1 << PIN_A_HIGH));
    pio_sm_set_pins_with_mask(msx_io_bus.pio_write, msx_io_bus.sm_write, 0/* (1 << PIN_A_HIGH) */, (1 << PIN_A_HIGH2));
#endif
    pio_sm_config cfg_io_read = msx_io_read_responder_program_get_default_config(msx_io_bus.offset_read);
#ifdef MUX_ADDR    
    sm_config_set_in_pins(&cfg_io_read, PIN_A8);
#else
    sm_config_set_in_pins(&cfg_io_read, PIN_A0);
#endif
    sm_config_set_in_shift(&cfg_io_read, false, false, 32);
    sm_config_set_out_shift(&cfg_io_read, true, false, 32);
    sm_config_set_jmp_pin(&cfg_io_read, PIN_RD);
    sm_config_set_clkdiv(&cfg_io_read, 1.0f);
#ifdef MUX_ADDR
    pio_sm_set_pins_with_mask(msx_io_bus.pio_read, msx_io_bus.sm_read, 0, (1 << PIN_A_HIGH));
#endif
    pio_sm_init(msx_io_bus.pio_read, msx_io_bus.sm_read, msx_io_bus.offset_read, &cfg_io_read);

    pio_sm_config cfg_io_write = msx_io_write_captor_program_get_default_config(msx_io_bus.offset_write);
#ifdef MUX_ADDR    
    sm_config_set_in_pins(&cfg_io_write, PIN_A8);
#else
    sm_config_set_in_pins(&cfg_io_write, PIN_A0);
#endif
    sm_config_set_in_shift(&cfg_io_write, false, false, 32);
    sm_config_set_out_shift(&cfg_io_write, true, false, 32);
    sm_config_set_fifo_join(&cfg_io_write, PIO_FIFO_JOIN_RX);
    sm_config_set_jmp_pin(&cfg_io_write, PIN_WR);
#ifdef MUX_ADDR    
    sm_config_set_set_pins(&cfg_io_write, PIN_A_HIGH2, 1);
#endif
    sm_config_set_clkdiv(&cfg_io_write, 1.0f);
    pio_sm_init(msx_io_bus.pio_write, msx_io_bus.sm_write, msx_io_bus.offset_write, &cfg_io_write);

    pio_sm_set_consecutive_pindirs(msx_io_bus.pio_read, msx_io_bus.sm_read, PIN_D0, 8, false);
    pio_sm_set_consecutive_pindirs(msx_io_bus.pio_write, msx_io_bus.sm_write, PIN_D0, 8, false);
#if 1
    //pio_gpio_init(msx_io_bus.pio_read, PIN_WAIT);
    //pio_gpio_init(msx_io_bus.pio_read, PIN_BUSDIR);
    //pio_sm_set_consecutive_pindirs(msx_io_bus.pio_read, msx_io_bus.sm_read, PIN_WAIT, 2, true);
#endif

    pio_sm_set_enabled(msx_io_bus.pio_read, msx_io_bus.sm_read, true);
    pio_sm_set_enabled(msx_io_bus.pio_write, msx_io_bus.sm_write, true);
}

// -----------------------------------------------------------------------
// Token helpers
// -----------------------------------------------------------------------

// Read a byte from the ROM, using SRAM cache when possible, flash otherwise.
static inline uint8_t __not_in_flash_func(read_rom_byte)(const uint8_t *rom_base, uint32_t rel)
{
    return (rel < rom_cached_size) ? rom_sram[rel] : rom_base[rel];
}

// Build a 16-bit token to send back to the read SM via TX FIFO.
//   bits[7:0]  = data byte
//   bits[15:8] = pindirs mask (0xFF = drive bus, 0x00 = tri-state)
static inline uint16_t __not_in_flash_func(pio_build_token)(bool drive, uint8_t data)
{
    uint8_t dir_mask = drive ? 0xFFu : 0x00u;
    return (uint16_t)data | ((uint16_t)dir_mask << 8);
}

// Try to consume a write event from the write captor FIFO.
// Returns false if FIFO is empty.
static __noinline bool __not_in_flash_func(pio_try_get_write)(uint16_t *addr_out, uint8_t *data_out)
{
    if (pio_sm_is_rx_fifo_empty(msx_bus.pio_write, msx_bus.sm_write))
        return false;

    uint32_t sample = pio_sm_get(msx_bus.pio_write, msx_bus.sm_write);
    *addr_out = (uint16_t)(sample & 0xFFFFu);
    *data_out = (uint8_t)((sample >> 16) & 0xFFu);
    return true;
}

// Drain all pending write events, invoking a handler for each.
static inline void __not_in_flash_func(pio_drain_writes)(void (*handler)(uint16_t addr, uint8_t data, void *ctx), void *ctx)
{
    uint16_t addr;
    uint8_t data;
    while (pio_try_get_write(&addr, &data))
    {
        handler(addr, data, ctx);
    }
}

// Try to consume an I/O write event from the I/O write captor FIFO (PIO1).
// Returns false if FIFO is empty.
static inline bool __not_in_flash_func(pio_try_get_io_write)(uint16_t *addr_out, uint8_t *data_out)
{
    if (pio_sm_is_rx_fifo_empty(msx_io_bus.pio_write, msx_io_bus.sm_write))
        return false;

    uint32_t sample = pio_sm_get(msx_io_bus.pio_write, msx_io_bus.sm_write);
#ifdef MUX_ADDR
    *addr_out = (uint16_t)(sample & 0xFFu);
    *data_out = (uint8_t)((sample >> 8) & 0xFFu);
#else
    *addr_out = (uint16_t)(sample & 0xFFFFu);
    *data_out = (uint8_t)((sample >> 16) & 0xFFu);
#endif
    return true;
}

// Map an 8-bit mapper register value to a valid mapper page index.
// 192KB mapper RAM provides 12 pages of 16KB each.
static inline uint8_t __not_in_flash_func(mapper_page_from_reg)(uint8_t reg)
{
    return (uint8_t)(reg % MAPPER_PAGES);
}

// Try to consume an I/O read event from the I/O read responder FIFO (PIO1).
// Returns false if FIFO is empty.
static inline bool __not_in_flash_func(pio_try_get_io_read)(uint16_t *addr_out)
{
    if (pio_sm_is_rx_fifo_empty(msx_io_bus.pio_read, msx_io_bus.sm_read))
        return false;

    *addr_out = (uint16_t)pio_sm_get(msx_io_bus.pio_read, msx_io_bus.sm_read);
    return true;
}

// Drain all pending I/O write events, invoking a handler for each.
static inline void __not_in_flash_func(pio_drain_io_writes)(void (*handler)(uint16_t addr, uint8_t data, void *ctx), void *ctx)
{
    uint16_t addr;
    uint8_t data;
    while (pio_try_get_io_write(&addr, &data))
    {
        handler(addr, data, ctx);
    }
}

// -----------------------------------------------------------------------
// Bank switching write handlers (used by mapper ROM types)
// -----------------------------------------------------------------------

// Context structures passed to write handlers
typedef struct {
    uint8_t *bank_regs;
} bank8_ctx_t;

typedef struct {
    uint16_t *bank_regs;
} bank16_ctx_t;

// Konami SCC write handler
static inline void __not_in_flash_func(handle_konamiscc_write)(uint16_t addr, uint8_t data, void *ctx)
{
    uint8_t *regs = ((bank8_ctx_t *)ctx)->bank_regs;
    if      (addr >= 0x5000u && addr <= 0x57FFu) regs[0] = data;
    else if (addr >= 0x7000u && addr <= 0x77FFu) regs[1] = data;
    else if (addr >= 0x9000u && addr <= 0x97FFu) regs[2] = data;
    else if (addr >= 0xB000u && addr <= 0xB7FFu) regs[3] = data;
}
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
int main()
{
    Start();
    return 0;
}

// -----------------------------------------------------------------------
// Main program
// -----------------------------------------------------------------------
int __no_inline_not_in_flash_func(Start)()
{
    // Set system clock to 230MHz for ROM loading timing headroom
    set_sys_clock_khz(230000, true);

#ifndef MUX_ADDR
    tusb_init();
#else
    tud_init(0);
#endif
    stdio_init_all();
    // Initialize GPIO
    setup_gpio();

    // Parse ROM header
    char rom_name[ROM_NAME_MAX];
    memcpy(rom_name, rom, ROM_NAME_MAX);
    uint8_t rom_type = 11;//rom[ROM_NAME_MAX];

    uint32_t rom_size = ___nextor_kernel_Nextor_2_1_4_SunriseIDE_MasterOnly_ROM_len;
    //memcpy(&rom_size, rom + ROM_NAME_MAX + 1, sizeof(uint32_t));
    active_rom_size = rom_size;

    // Load the ROM based on the detected mapper type
    // 1 - 16KB ROM
    // 2 - 32KB ROM
    // 3 - Konami SCC ROM
    // 4 - Planar48 ROM
    // 5 - ASCII8 ROM
    // 6 - ASCII16 ROM
    // 7 - Konami (without SCC) ROM
    // 8 - NEO8 ROM
    // 9 - NEO16 ROM
    // 10 - Sunrise IDE Nextor ROM (SYSTEM)
    // 11 - Sunrise IDE Nextor ROM + 128KB Memory Mapper
    // 12 - ASCII16-X ROM
    // 13 - Planar64 ROM
    // 14 - Manbow2 (Konami SCC + AMD flash)
    switch (rom_type) 
    {
        case 1:
        case 2:
            loadrom_planar32(ROM_RECORD_SIZE, true); 
            break;
        case 3:
            loadrom_konamiscc(ROM_RECORD_SIZE, true); 
            break;
        case 4:
            loadrom_planar48(ROM_RECORD_SIZE, true); 
            break;
        case 5:
            loadrom_ascii8(ROM_RECORD_SIZE, true); 
            break;
        case 6:
            loadrom_ascii16(ROM_RECORD_SIZE, true); 
            break;
        case 7:
            loadrom_konami(ROM_RECORD_SIZE, true); 
            break;
        case 8:
            loadrom_neo8(ROM_RECORD_SIZE);
            break;
        case 9:
            loadrom_neo16(ROM_RECORD_SIZE);
            break;
        case 10:
            loadrom_sunrise(ROM_RECORD_SIZE, true);
            break;
        case 11:
            loadrom_sunrise_mapper(0/* ROM_RECORD_SIZE */, true);
            break;
        case 12:
            loadrom_ascii16x(ROM_RECORD_SIZE, true);
            break;
        case 13:
            loadrom_planar64(ROM_RECORD_SIZE, true);
            break;
        case 14:
            loadrom_manbow2(ROM_RECORD_SIZE, true);
            break;
        default:
            break;
    }
    return 0;
}

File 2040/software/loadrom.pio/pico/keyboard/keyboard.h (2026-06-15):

// MSX PICOVERSE PROJECT
// (c) 2026 Cristiano Goncalves
// The Retro Hacker
//
// keyboard.h - Pin definitions and constants for MSX PicoVerse USB Keyboard firmware
//
// This work is licensed under a "Creative Commons Attribution-NonCommercial-ShareAlike 4.0 International
// License". https://creativecommons.org/licenses/by-nc-sa/4.0/

#ifndef KEYBOARD_H
#define KEYBOARD_H

// -----------------------------------------------------------------------
// GPIO pin assignments (directly mapped to MSX bus signals)
// -----------------------------------------------------------------------
// Address lines (A0-A15)
#define PIN_A0     0
#define PIN_A1     1
#define PIN_A2     2
#define PIN_A3     3
#define PIN_A4     4
#define PIN_A5     5
#define PIN_A6     6
#define PIN_A7     7
#define PIN_A8     8
#define PIN_A9     9
#define PIN_A10    10
#define PIN_A11    11
#define PIN_A12    12
#define PIN_A13    13
#define PIN_A14    14
#define PIN_A15    15

// Data lines (D0-D7)
#define PIN_D0     16
#define PIN_D1     17
#define PIN_D2     18
#define PIN_D3     19
#define PIN_D4     20
#define PIN_D5     21
#define PIN_D6     22
#define PIN_D7     23

// Control signals
#define PIN_RD     24   // /RD   — active-low read strobe
#define PIN_WR     25   // /WR   — active-low write strobe
#define PIN_IORQ   26   // /IORQ — active-low I/O request
#define PIN_SLTSL  27   // /SLTSL — active-low slot select (unused by keyboard)
#define PIN_WAIT   28   // /WAIT  — active-low, driven by PIO to freeze Z80 during I/O reads
#define PIN_BUSDIR 29  // BUSSDIR — bus direction control (unused by keyboard)

#define PICO_FLASH_SPI_CLKDIV 2

#endif

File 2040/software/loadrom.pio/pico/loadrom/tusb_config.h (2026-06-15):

/*
 * The MIT License (MIT)
 *
 * Copyright (c) 2019 Ha Thach (tinyusb.org)
 *
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
 */

#ifndef _TUSB_CONFIG_H_
#define _TUSB_CONFIG_H_

#ifdef __cplusplus
 extern "C" {
#endif

//--------------------------------------------------------------------
// COMMON CONFIGURATION
//--------------------------------------------------------------------

// defined by compiler flags for flexibility
#ifndef CFG_TUSB_MCU
#error CFG_TUSB_MCU must be defined
#endif

#define CFG_TUSB_RHPORT0_MODE       OPT_MODE_HOST

#ifndef CFG_TUSB_OS
#define CFG_TUSB_OS                 OPT_OS_NONE
#endif

#ifndef CFG_TUSB_DEBUG
#define CFG_TUSB_DEBUG        0
#endif

/* USB DMA on some MCUs can only access a specific SRAM region with restriction on alignment.
 * Tinyusb use follows macros to declare transferring memory so that they can be put
 * into those specific section.
 * e.g
 * - CFG_TUSB_MEM SECTION : __attribute__ (( section(".usb_ram") ))
 * - CFG_TUSB_MEM_ALIGN   : __attribute__ ((aligned(4)))
 */
#ifndef CFG_TUH_MEM_SECTION
#define CFG_TUH_MEM_SECTION
#endif

#ifndef CFG_TUSB_MEM_ALIGN
#define CFG_TUSB_MEM_ALIGN          __attribute__ ((aligned(4)))
#endif

//--------------------------------------------------------------------
// Host Configuration
//--------------------------------------------------------------------

// Enable Host stack
#define CFG_TUH_ENABLED       1
#define CFG_TUD_ENABLED       1

#if CFG_TUSB_MCU == OPT_MCU_RP2040
  // #define CFG_TUH_RPI_PIO_USB   1 // use pio-usb as host controller
  // #define CFG_TUH_MAX3421       1 // use max3421 as host controller

  // host roothub port is 1 if using either pio-usb or max3421
  #if (defined(CFG_TUH_RPI_PIO_USB) && CFG_TUH_RPI_PIO_USB) || (defined(CFG_TUH_MAX3421) && CFG_TUH_MAX3421)
    #define BOARD_TUH_RHPORT      1
  #endif
#endif

// Default is max speed that hardware controller could support with on-chip PHY
#define CFG_TUH_MAX_SPEED     BOARD_TUH_MAX_SPEED

//------------------------- Board Specific --------------------------

// RHPort number used for host can be defined by board.mk, default to port 0
#ifndef BOARD_TUH_RHPORT
#define BOARD_TUH_RHPORT      0
#endif

// RHPort max operational speed can defined by board.mk
#ifndef BOARD_TUH_MAX_SPEED
#define BOARD_TUH_MAX_SPEED   OPT_MODE_DEFAULT_SPEED
#endif

//--------------------------------------------------------------------
// Driver Configuration
//--------------------------------------------------------------------

// Size of buffer to hold descriptors and other data used for enumeration
#define CFG_TUH_ENUMERATION_BUFSIZE 256

#define CFG_TUH_HUB                 1 // number of supported hubs
#define CFG_TUH_CDC                 0 // CDC ACM
#define CFG_TUH_HID                 0 //(3*CFG_TUH_DEVICE_MAX) // typical keyboard + mouse device can have 3-4 HID interfaces
#define CFG_TUH_MIDI                0
#define CFG_TUH_MSC                 1
#define CFG_TUH_VENDOR              0

// max device support (excluding hub device): 1 hub typically has 4 ports
#define CFG_TUH_DEVICE_MAX          (CFG_TUH_HUB ? 4 : 1)

//------------- HID -------------//
#define CFG_TUH_HID_EPIN_BUFSIZE    64
#define CFG_TUH_HID_EPOUT_BUFSIZE   64

//------------- CDC -------------//

// Set Line Control state on enumeration/mounted:
// DTR ( bit 0), RTS (bit 1)
//#define CFG_TUH_CDC_LINE_CONTROL_ON_ENUM    0x03

// Set Line Coding on enumeration/mounted, value for cdc_line_coding_t
// bit rate = 115200, 1 stop bit, no parity, 8 bit data width
//#define CFG_TUH_CDC_LINE_CODING_ON_ENUM   { 115200, CDC_LINE_CODING_STOP_BITS_1, CDC_LINE_CODING_PARITY_NONE, 8 }

#define CFG_TUD_CDC 1
#define CFG_TUD_CDC_RX_BUFSIZE 1024
#define CFG_TUD_CDC_TX_BUFSIZE 1024

#ifdef __cplusplus
 }
#endif

#endif /* _TUSB_CONFIG_H_ */

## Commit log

2026-05-18 - Removed Konami SCC and Manbow2 from the supported MSX-MUSIC/FM-PAC mapper set; the LoadROM tool now rejects `-f` / `-fmpac` for those ROMs and the firmware FM-PAC wrapper no longer carries SCC-clas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
    [loadrom.c, loadrom.h]
2026-05-22 Update kicad
    [PicoVerse2040.kicad_sch]
2026-05-22 Revert "Merge branch 'main' of https://github.com/tchv71/msx-picoverse-public"
    This reverts commit a3ed62548e82abeba98711e7134bc43e69b952c0, reversing
    changes made to 5d39053092ba99a309041cc20d9bcc0b0da891bb.
    [PicoVerse2040.kicad_sch]
2026-05-26 Fix MREQ <-> IORQ
    [PicoVerse2040.kicad_sch]
2026-05-26 Fix bugs
    [PicoVerse2040.kicad_sch]
2026-06-10 Fix pcb
    [PicoVerse2040.kicad_pcb, PicoVerse2040.kicad_sch]
2026-06-21 Working 2
    [PicoVerse2040-kp11.kicad_sch]
2026-07-11 Working 7
    [PicoVerse2040-kp11.kicad_sch]
2026-07-23 Make MUX_ADDR working
    [PicoVerse2040-kp11.kicad_sch]
2026-07-26 Add SD to MUX_ADDR
    [PicoVerse2040-kp11.kicad_sch]
2026-08-03 Fix COM buffer overflow
    [loadrom.c]
